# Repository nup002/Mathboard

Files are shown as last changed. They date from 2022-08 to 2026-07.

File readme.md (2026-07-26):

# Mathpad
### Get yours on [Crowd Supply](https://www.crowdsupply.com/summa-cogni/mathpad) or [Tindie](https://www.tindie.com/products/summacogni/mathpad/)
<div align="center">
  <table border="0" cellspacing="0" cellpadding="0" style="border-collapse: collapse;">
    <tr>
      <td align="center" width="33%" style="border: none;">
        <a href="https://mathpad.summacogni.com">
          Documentation
        </a><br>
        <p>Learn more about Mathpad with the 
        <a href="https://mathpad.summacogni.com">Official Documentation</a>.</p>
      </td>
      <td align="center" width="33%" style="border: none;">
        <a href="https://www.summacogni.com/forum/viewforum.php?f=3&sid=dd5691a11e42b75db93c227916b067e8">
          Forum
        </a><br>
        <p>Chat with other users and ask your questions in the
        <a href="https://www.summacogni.com/forum/viewforum.php?f=3&sid=dd5691a11e42b75db93c227916b067e8">Forum</a>.</p>
      </td>
      <td align="center" width="33%" style="border: none;">
        <a href="https://x.com/SummaCogni">
          Twitter/X
        </a><br>
        <p>Get the latest updates about Mathpad on
        <a href="https://x.com/SummaCogni">Twitter/X</a>.</p>
      </td>
    </tr>
  </table>
</div>
<p align="center">
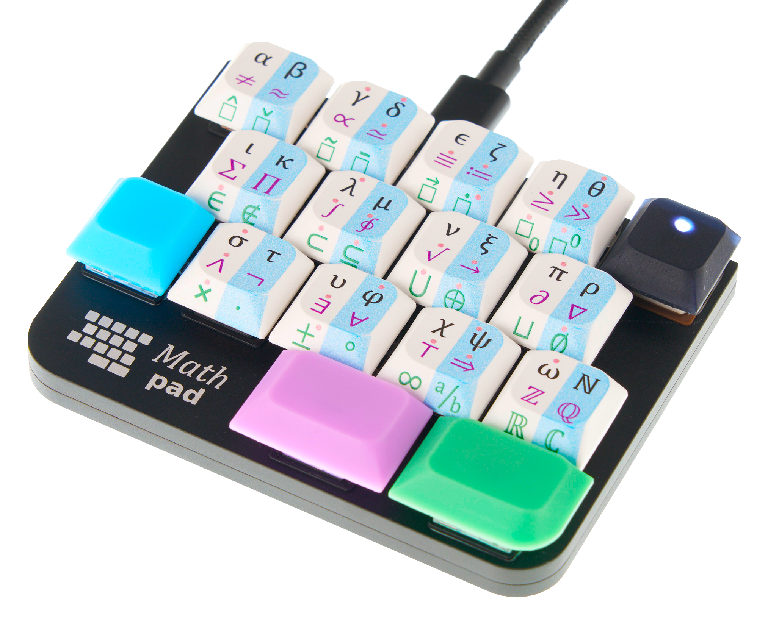
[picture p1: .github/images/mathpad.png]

</p>

## What is it?
Mathpad is a keypad that makes it easy to type equations. It is intended for engineers, 
scientists, students, and professionals in STEM fields who regularly need to write equations or who use 
mathematical symbols in their day-to-day work. 

With the Mathpad you can type 120 symbols from algebra, calculus, set theory, and 
logic, and the full greek alphabet. Mathpad plugs into your computer with a USB-C cable and 
works seamlessly alongside your regular keyboard.

The following equations are a few examples of what you can 
type directly with the Mathpad:

<p style="text-align: center;"><font size="4"> 
E = mc²<br>
∛β ≫ ∯Ω(t)dt<br>
(A⊂B) ∧ (A⊂C) ⇔ A ⊂ (B ∪ C)
</font> </p>

## Where to buy
Mathpad is available now on [Crowd Supply](https://www.crowdsupply.com/summa-cogni/mathpad) and [Tindie](https://www.tindie.com/products/summacogni/mathpad/).

### Which site should I use?
- USA customers: Buy from Crowd Supply
- International customers: Buy from Tindie

### Why the price difference?
Crowd Supply is a US-based reseller that handles distribution but must factor in import tariffs and retail margins, which increases the price. Tindie is a marketplace where I sell directly to you with lower platform fees and no US import tariffs for international buyers, resulting in a lower price.

## Compatibility
Mathpad works on Windows, macOS, and virtually all Unix systems.

Several output modes are supported. Plaintext outputs standard Unicode symbols and can be used practically anywhere you can type regular text. LaTeX is 
of course also supported, as well as the equation editors of Microsoft Office and LibreOffice.
| Output mode | Supported |
|---|---|
| Plaintext | ✅ |
| LaTeX | ✅ |
| Microsoft Office equation editor | ✅ |
| LibreOffice equation editor | ✅ |

Mathpad works on all computers with Latin keyboard layouts. This includes nearly all western layouts, including 
US ANSI, UK, French AZERTY, DVORAK, and many more. For a full list of all supported keyboard layouts, 
see [this list](https://mathpad.summacogni.com/#/compatibility?id=supported-keyboard-layouts).

## Firmware releases
Official releases are located in [releases](https://github.com/Summa-Cogni/Mathpad/releases). The most recent version can always be found [here](https://mathpad.summacogni.com/#/firmware-download).

If you wish to build the firmware binaries yourself, follow [this guide](https://mathpad.summacogni.com/#/firmware_prerequisites) from the official documentation.

## Licenses
<p align="center">

</p>

Everyone is permitted to replicate the Mathpad based on the design files found in this repository. Everyone is
 permitted to modify, share, and distribute the files, as long as the terms set out in the licenses are respected.

The Summa Cogni logo and the Mathpad logo are the properties of Summacogni OÜ, and may not be replicated.

The OSHWA certification ID `UK000074` is issued to Summacogni OÜ, and may not be replicated.

## Certifications
Mathpad is [certified](https://certification.oshwa.org/uk000074.html) by the Open Source Hardware Association.
<p align="center">
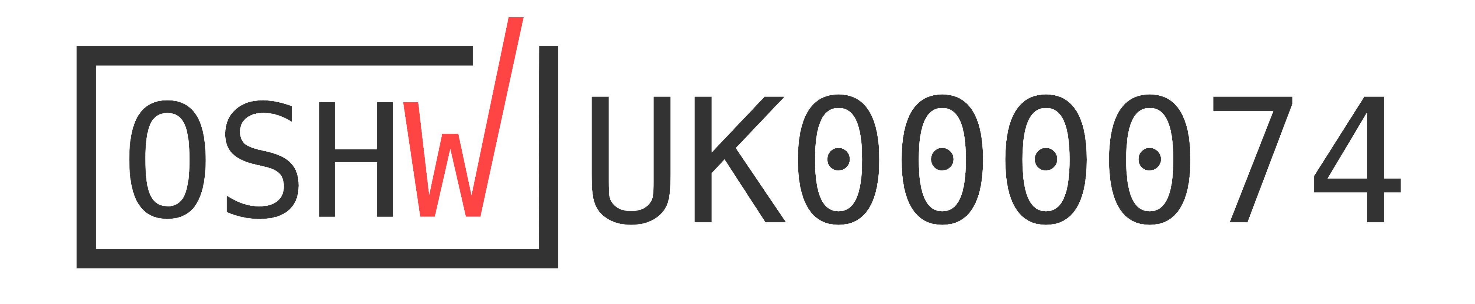
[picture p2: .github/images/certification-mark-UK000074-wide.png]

</p>

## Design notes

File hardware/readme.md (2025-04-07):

# Hardware resources

This folder contains everything related to the hardware of the Mathpad:
- Enclosure
- Keycaps
- Printed circuit board

The files contained in this folder are licensed under [CERN Open Hardware Licence Version 2 - Strongly Reciprocal](https://cern-ohl.web.cern.ch).

## What you CAN do:
- Use the design files to make products for yourself
- Modify the design files to suit your needs
- Share and distribute the original design files
- Share and distribute your modified design files
- Use the designs commercially and sell products you make

## What you MUST do:
- Keep all the original license notices and copyright information
- If you modify the files, add a notice stating what you changed and when
- When sharing products you've made, you must either:
	1) Provide the complete source files with the product, OR
	2) Clearly inform recipients where they can get the complete source files
- License any modifications you make under the same CERN-OHL-S license
- Display the source location on the product itself if specified in a notice

## What you CANNOT do:
- Remove or alter the original license notices
- Use a different license for your modifications
- Restrict others from exercising the rights granted by this license
- Hold the original creators liable for any issues with the designs

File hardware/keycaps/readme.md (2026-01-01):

# Keycaps

This folder contains the design files required to create the keycaps.

Symbol keycaps
-----------
The symbol keys use JWA keycap profiles. These can be purchased online or 3D printed using `cad files\JWA-1u.stl`. 
The decals are located in the `decals` folder and must be UV-printed onto the keycaps.

Modifier keycaps
-------------
The bottom modifier switches use 1.5u JWA keycap profiles. These must be 3D printed using `cad files\JWA-1-5u.stl` and `cad files\JWA-1-5u-rounded.stl`.

Mode switch keycap
------------------
The mode switch keycap consist of two pieces that click together: `cad files\JWA-1u-Mode-Switch.stl` and `cad files\Mode-Switch-Insert.stl`.

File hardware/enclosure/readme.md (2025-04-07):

# Mathpad enclosure

This folder contains all design files for the aluminum enclosure of the Mathpad. 

CAD files are provided in `.step` format and are located in the folder `cad files`.

Laser engraving files are provided in `.svg` format and are located in the folder `laser engraving`.

## Manufacturing specifications
- Material	: Aluminium 6061 or similar
- Surface 	: As machined
- Finish  	: Matte black anodization with laser marking
- Tapped holes  : 4 M2x0.4
- Tolerances	: ISO2768 medium

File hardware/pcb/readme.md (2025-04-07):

Mathpad PCB
###########

This folder contains the schematics and design files for the Mathpad PCB.

The folder `kicad` contains the full KiCAD project file. Download the open source [KiCAD EDA](https://www.kicad.org) to open it.

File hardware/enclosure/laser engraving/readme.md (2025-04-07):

# Laser engraving

This folder contains the file `mathpad_laser_engraving_back.svg` which is used to perform laser engraving of the 
symbols, labels, and other features on the back of the Mathpad.

The folder `enclosure outlines` contain SVG files of the outline of the Mathpad as seen from the top and the bottom, 
and can be used for developing new laser engraving designs.

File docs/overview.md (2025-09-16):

# Overview

On the back there is the OS switch, an LED indicating if the 
Mathpad is powered, and the USB-C port.



The top of Mathpad has many keys. There are 3 rows of symbol keys, three colored Modifier keys, and the  
[Mode key](/modes.md).



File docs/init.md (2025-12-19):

# Initial Setup

**Mathpad works straight out of the box in many cases.** But depending on your operating system and keyboard layout, 
there are a few initial tasks that may have to be performed. Follow this short guide to get your Mathpad up and running.

## What operating system do you use?

<!-- tabs:start -->
#### **Mac**

1) Install [Mathpad Service](https://github.com/Summa-Cogni/Mathpad/releases/download/mathpad-service-v1.1.0/mathpad-service-1.1.0.dmg) - this small application enables Mathpad to insert Unicode symbols on Mac.
2) Set the OS switch on the back of your Mathpad to the MAC position

#### **Windows**

1) Install [WinCompose](http://wincompose.info) - this enables special character input on Windows
2) Set the OS switch on the back of your Mathpad to the WINDOWS position

> [!TIP]
> If you cannot install WinCompose, for example if your computer is managed by an IT department and you 
> lack administrator rights, use the [portable executable](https://github.com/samhocevar/wincompose/releases/download/v0.9.10/WinCompose-NoInstall-0.9.10.zip).
> 
> 

#### **Linux**

1) Set the OS switch on the back of your Mathpad to the LINUX position

There's no software to install on Linux, as most distros have built-in support for Unicode input.
> 
<!-- tabs:end -->

> [!NOTE|label:Why Setting The OS Switch Is Required]
> Mathpad transmits symbols using Unicode. Since each operating system handles Unicode input differently, Mathpad needs 
> to adjust its data format based on the connected operating system. USB devices like Mathpad cannot detect your 
> computer's operating system automatically, so you must specify it with the OS switch.
> 
> 
## What is your keyboard layout?
<!-- tabs:start -->

#### **US ANSI (standard layout in USA)**

You're good to go! Mathpad supports US ANSI out of the box. You can move on to [Getting Started](/get_started.md).

> [!TIP]
> You may still want to update your Mathpad's firmware to the newest version to benefit from 
> new features and bugfixes. Do so by following the instructions in the [Firmware Update Guide](update_firmware.md).
> 

#### **Any other layout**

**You must update your Mathpad's firmware to match your computer's keyboard layout.** 
1) Follow the instructions in the [Firmware Update Guide](update_firmware.md)
2) Once you've updated your Mathpad's firmware, move on to [Getting Started](/get_started.md).

> [!TIP]
>Your keyboard layout is usually defined in the "Input devices" or "Language and Region" settings. Check out this 
> [guide](/compatibility.md#how-to-check-your-layout) if you need some extra help.
> 
<!-- tabs:end -->

> [!NOTE|label:Why Layout Matching Is Required]
>Your Mathpad's firmware must match your computer's keyboard layout. This is necessary because operating systems 
> interpret keyboard signals differently based on layout settings, and USB devices like Mathpad cannot detect your 
> computer's layout automatically. 
> 
> Keyboards do not send actual letters. Instead they send 'keycodes' which are interpreted into symbols by the 
> OS. When a Norwegian keyboard user clicks the key for 'å', the letter 'å' is never sent. Instead, the keyboard sends 
> the keycode for 'left bracket' (`[`) which is then interpreted as 'å' by the OS.

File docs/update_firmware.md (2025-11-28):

# Updating the Firmware

Firmware is the code that runs on the processor inside the Mathpad. You must sometimes update this firmware, 
for example when:
- You set up your Mathpad for the first time
- You change the keyboard layout on your computer
- You want to use a feature in a new firmware release
- You make your own modifications to the firmware

> [!TIP|label: Get your current firmware version]
> In a text editor, keep all the modifier keys ([R], [C] and [B]) pressed for at least 5 seconds, then release them.
> Your Mathpad will type a lot of information about itself, including its firmware version.
> 

**Updating the Mathpad firmware is safe and very simple**. It requires no previous experience or special 
tools. Just follow these three steps:

### Step 1: Download your firmware
Head over to the [Firmware Download](firmware-download.md) page and download the firmware that matches your keyboard 
layout.

### Step 2: Put your Mathpad in firmware upload mode
With your Mathpad plugged in, flip it over and use something long and thin (e.g. a pen) to press the 
Restart button for at least half a second, then release it. The Restart button is located here:



### Step 3: Drag and drop the firmware file
When you release the Restart button, a folder named `RPI-RP2` with a two files inside should appear automatically on 
your computer. Grab the firmware file you just downloaded, and drag-and-drop (or copy-paste) it to the `RPI-RP2` 
folder. Once the file has been transferred, the folder will close automatically. You're done!

> [!TIP|label:No RPI-RP2 folder]
> If the `RPI-RP2` folder does not appear, try keeping the Restart button pressed longer before releasing it. You 
> should also look under "This PC" on Windows, or "Computer" on Mac.
>

> [!TIP]
> The Mathpad is **not** a storage device like a USB memory stick - do not expect to find the firmware file in the 
> `RPI-RP2` folder after you have uploaded it.
>

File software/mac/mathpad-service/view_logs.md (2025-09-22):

# View current logs
tail -f /usr/local/var/log/mathpad-service.log

# View error logs  
tail -f /usr/local/var/log/mathpad-service.error.log

# Start service manually
/usr/local/bin/start-mathpad-service

# Stop service
pkill -f mathpad-service

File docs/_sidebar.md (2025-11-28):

- Quick Start
  * [Initial Setup](init.md "Setting up your Mathpad for the first time")
  * [Getting Started](get_started.md "Getting started with using your Mathpad")
  * [Device Overview](overview.md "What's what on Mathpad")

- User Guide
  * [Symbols Reference](symbols.md "A comprehensive list of all Mathpad symbols")
  * [Multitap Feature](multitap.md "Access hidden symbols")
  * [Output Modes](modes.md "Switch between Plaintext, LaTeX, and more")
  * [Update Firmware](update_firmware.md "Update the firmware of your Mathpad")
  * [Troubleshooting](troubleshoot.md "Fix common problems")
  * [Compatibility](compatibility.md "View OS and keyboard layout compatibility")

- Downloads
  * [Firmware](firmware-download.md "Download Mathpad firmware")
  * [Software](software-download.md "Download Mathpad software")

- Advanced Topics
  * [Firmware Prerequisites](firmware_prerequisites.md "Get ready to modify the Mathpad firmware")
  * [Firmware Manual](firmware.md "Learn how to modify the Mathpad firmware")
  * [Firmware Compilation](compile.md "Learn how to compile the Mathpad firmware")

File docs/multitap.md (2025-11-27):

# Multitap

Many symbols are marked by a small orange dot. Tapping such a symbol twice quickly will type a different 
but related symbol. For example, double-tapping <keycombo>[δ]</keycombo> types its uppercase variant Δ. The notation 
for this action is <keycombo>[δ][x2]</keycombo>.



Certain symbols can be triple-tapped. For example, to type ∜ you must triple-tap <keycombo>[√]</keycombo>. 
Double-tapping it types ∛.

To multitap a symbol that requires the use of modifier keys, you must keep the modifier keys pressed and only multitap 
the symbol key. For example, to get ≅, you must keep [R] and [C] pressed while you tap <keycombo>[≃]</keycombo> twice 
quickly.

Try multitapping some symbols in the text editor below to get used to it. 
<div class="keyboard-test-container">
  <div class="input-area">
    <textarea rows="1" cols="20" style="font-family:'Cambria Math';font-size: 30pt"></textarea>
  </div>
</div>

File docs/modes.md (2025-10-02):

# Output Modes

The default output mode of Mathpad is Plaintext. In Plaintext mode, Mathpad outputs simple Unicode symbols. This mode 
is the most versatile, and works with virtually all text editors. Mathpad is in Plaintext mode when the Mode key 
lights white.

> [!TIP]
> Change the mode key brightness by tapping it while holding down the purple or green modifier keys.
>

If you are instead working in the typesetting language LaTeX, or using the equation editors of Microsoft Office or 
LibreOffice, you'll want to switch modes by clicking the Mode key:

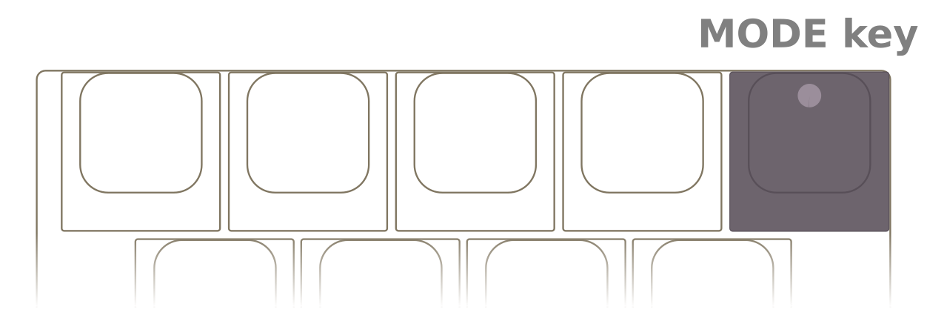
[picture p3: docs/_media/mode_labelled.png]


## LaTeX mode
**Set LaTeX mode by clicking the Mode key until it lights magenta.**

In LaTeX mode, Mathpad will type LaTeX codes. Test it here:

<div class="keyboard-test-container">
  <div class="input-area">
    <textarea id="latex-input" rows="1" cols="50" placeholder="Click here and type"></textarea>
  </div>
  <div class="render-area">
    
  </div>
</div>

<style>
.keyboard-test-container {
  margin: 20px 0;
  display: flex;
  flex-direction: column;
  gap: 15px;
}
.input-area, .render-area {
  width: 100%;
}
#latex-input {
  width: 100%;
  padding: 10px;
  font-family: monospace;
  border: 1px solid #ccc;
  border-radius: 4px;
}
#latex-output {
  padding: 15px;
  min-height: 100px;
  border: 1px solid #eee;
  border-radius: 4px;
  background: #f9f9f9;
  font-size: 3em; /* Adjust the size as needed */
}
</style>

> [!TIP]
> You can always get Mathpad back to Plaintext mode by holding down the Mode key for one second and releasing it.
>

## Microsoft Office Equation Editor mode
**Set Microsoft Office mode by clicking the Mode key until it lights blue.** 

In this mode, Mathpad will type codes 
that works specifically with the equation editor that is built into many Microsoft Office applications, such as Word.

## LibreOffice Equation Editor mode
**Set LibreOffice mode by clicking the Mode key until it lights green.**

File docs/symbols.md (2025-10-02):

# Mathpad Symbols

Every symbol that can be typed with the Mathpad is listed here. 

## Lowercase Greek Letters
<div class="symbols-grid">
  <div class="symbol-card">
    <div class="symbol">α</div>
    <div class="name">Alpha</div>
    <div class="details">
      <div class="key-combo"><keycombo>[α]</keycombo></div>
    </div>
  </div>
  <div class="symbol-card">
    <div class="symbol">β</div>
    <div class="name">Beta</div>
    <div class="details">
      <div class="key-combo"><keycombo>[R]+[α]</keycombo></div>
    </div>
  </div>
  <div class="symbol-card">
    <div class="symbol">γ</div>
    <div class="name">Gamma</div>
    <div class="details">
      <div class="key-combo"><keycombo>[γ]</keycombo></div>
    </div>
  </div>
  <div class="symbol-card">
    <div class="symbol">δ</div>
    <div class="name">Delta</div>
    <div class="details">
      <div class="key-combo"><keycombo>[R]+[γ]</keycombo></div>
    </div>
  </div>
  <div class="symbol-card">
    <div class="symbol">ϵ</div>
    <div class="name">Epsilon</div>
    <div class="details">
      <div class="key-combo"><keycombo>[ϵ]</keycombo></div>
    </div>
  </div>
  <div class="symbol-card">
    <div class="symbol">ζ</div>
    <div class="name">Zeta</div>
    <div class="details">
      <div class="key-combo"><keycombo>[R]+[ϵ]</keycombo></div>
    </div>
  </div>
  <div class="symbol-card">
    <div class="symbol">η</div>
    <div class="name">Eta</div>
    <div class="details">
      <div class="key-combo"><keycombo>[η]</keycombo></div>
    </div>
  </div>
  <div class="symbol-card">
    <div class="symbol">θ</div>
    <div class="name">Theta</div>
    <div class="details">
      <div class="key-combo"><keycombo>[R]+[η]</keycombo></div>
    </div>
  </div>
  <div class="symbol-card">
    <div class="symbol">ι</div>
    <div class="name">Iota</div>
    <div class="details">
      <div class="key-combo"><keycombo>[ι]</keycombo></div>
    </div>
  </div>
  <div class="symbol-card">
    <div class="symbol">κ</div>
    <div class="name">Kappa</div>
    <div class="details">
      <div class="key-combo"><keycombo>[R]+[κ]</keycombo></div>
    </div>
  </div>
  <div class="symbol-card">
    <div class="symbol">λ</div>
    <div class="name">Lambda</div>
    <div class="details">
      <div class="key-combo"><keycombo>[λ]</keycombo></div>
    </div>
  </div>
  <div class="symbol-card">
    <div class="symbol">μ</div>
    <div class="name">Mu</div>
    <div class="details">
      <div class="key-combo"><keycombo>[R]+[μ]</keycombo></div>
    </div>
  </div>
  <div class="symbol-card">
    <div class="symbol">ν</div>
    <div class="name">Nu</div>
    <div class="details">
      <div class="key-combo"><keycombo>[ν]</keycombo></div>
    </div>
  </div>
  <div class="symbol-card">
    <div class="symbol">ξ</div>
    <div class="name">Xi</div>
    <div class="details">
      <div class="key-combo"><keycombo>[R]+[ξ]</keycombo></div>
    </div>
  </div>
  <div class="symbol-card">
    <div class="symbol">π</div>
    <div class="name">Pi</div>
    <div class="details">
      <div class="key-combo"><keycombo>[π]</keycombo></div>
    </div>
  </div>
  <div class="symbol-card">
    <div class="symbol">ρ</div>
    <div class="name">Rho</div>
    <div class="details">
      <div class="key-combo"><keycombo>[R]+[ρ]</keycombo></div>
    </div>
  </div>
  <div class="symbol-card">
    <div class="symbol">σ</div>
    <div class="name">Sigma</div>
    <div class="details">
      <div class="key-combo"><keycombo>[σ]</keycombo></div>
    </div>
  </div>
  <div class="symbol-card">
    <div class="symbol">τ</div>
    <div class="name">Tau</div>
    <div class="details">
      <div class="key-combo"><keycombo>[R]+[τ]</keycombo></div>
    </div>
  </div>
  <div class="symbol-card">
    <div class="symbol">υ</div>
    <div class="name">Upsilon</div>
    <div class="details">
      <div class="key-combo"><keycombo>[υ]</keycombo></div>
    </div>
  </div>
  <div class="symbol-card">
    <div class="symbol">φ</div>
    <div class="name">Phi</div>
    <div class="details">
      <div class="key-combo"><keycombo>[R]+[φ]</keycombo></div>
    </div>
  </div>
  <div class="symbol-card">
    <div class="symbol">χ</div>
    <div class="name">Chi</div>
    <div class="details">
      <div class="key-combo"><keycombo>[χ]</keycombo></div>
    </div>
  </div>
  <div class="symbol-card">
    <div class="symbol">ψ</div>
    <div class="name">Psi</div>
    <div class="details">
      <div class="key-combo"><keycombo>[R]+[ψ]</keycombo></div>
    </div>
  </div>
  <div class="symbol-card">
    <div class="symbol">ω</div>
    <div class="name">Omega</div>
    <div class="details">
      <div class="key-combo"><keycombo>[ω]</keycombo></div>
    </div>
  </div>
</div>

## Uppercase Greek Letters
<div class="symbols-grid">
  <div class="symbol-card">
    <div class="symbol">Γ</div>
    <div class="name">Gamma (uppercase)</div>
    <div class="details">
      <div class="key-combo"><keycombo>[γ][x2]</keycombo></div>
    </div>
  </div>
  <div class="symbol-card">
    <div class="symbol">Δ</div>
    <div class="name">Delta (uppercase)</div>
    <div class="details">
      <div class="key-combo"><keycombo>[R]+[δ][x2]</keycombo></div>
    </div>
  </div>
  <div class="symbol-card">
    <div class="symbol">Θ</div>
    <div class="name">Theta (uppercase)</div>
    <div class="details">
      <div class="key-combo"><keycombo>[R]+[θ][x2]</keycombo></div>
    </div>
  </div>
  <div class="symbol-card">
    <div class="symbol">Λ</div>
    <div class="name">Lambda (uppercase)</div>
    <div class="details">
      <div class="key-combo"><keycombo>[λ][x2]</keycombo></div>
    </div>
  </div>
  <div class="symbol-card">
    <div class="symbol">Ξ</div>
    <div class="name">Xi (uppercase)</div>
    <div class="details">
      <div class="key-combo"><keycombo>[R]+[ξ][x2]</keycombo></div>
    </div>
  </div>
  <div class="symbol-card">
    <div class="symbol">Π</div>
    <div class="name">Pi (uppercase)</div>
    <div class="details">
      <div class="key-combo"><keycombo>[π][x2]</keycombo></div>
    </div>
  </div>
  <div class="symbol-card">
    <div class="symbol">Σ</div>
    <div class="name">Sigma (uppercase)</div>
    <div class="details">
      <div class="key-combo"><keycombo>[σ][x2]</keycombo></div>
    </div>
  </div>
  <div class="symbol-card">
    <div class="symbol">Φ</div>
    <div class="name">Phi (uppercase)</div>
    <div class="details">
      <div class="key-combo"><keycombo>[R]+[φ][x2]</keycombo></div>
    </div>
  </div>
  <div class="symbol-card">
    <div class="symbol">Ψ</div>
    <div class="name">Psi (uppercase)</div>
    <div class="details">
      <div class="key-combo"><keycombo>[R]+[ψ][x2]</keycombo></div>
    </div>
  </div>
  <div class="symbol-card">
    <div class="symbol">Ω</div>
    <div class="name">Omega (uppercase)</div>
    <div class="details">
      <div class="key-combo"><keycombo>[ω][x2]</keycombo></div>
    </div>
  </div>
</div>

## Relationships
<div class="symbols-grid">
  <div class="symbol-card">
    <div class="symbol">≠</div>
    <div class="name">Not equal</div>
    <div class="details">
      <div class="key-combo"><keycombo>[C]+[α]</keycombo></div>
    </div>
  </div>
  <div class="symbol-card">
    <div class="symbol">≈</div>
    <div class="name">Approximately equal</div>
    <div class="details">
      <div class="key-combo"><keycombo>[R][C]+[α]</keycombo></div>
    </div>
  </div>
  <div class="symbol-card">
    <div class="symbol">∝</div>
    <div class="name">Proportional to</div>
    <div class="details">
      <div class="key-combo"><keycombo>[C]+[γ]</keycombo></div>
    </div>
  </div>
  <div class="symbol-card">
    <div class="symbol">≃</div>
    <div class="name">Asymptotically equal</div>
    <div class="details">
      <div class="key-combo"><keycombo>[R][C]+[γ]</keycombo></div>
    </div>
  </div>
  <div class="symbol-card">
    <div class="symbol">≅</div>
    <div class="name">Approximately equal</div>
    <div class="details">
      <div class="key-combo"><keycombo>[R][C]+[γ][x2]</keycombo></div>
    </div>
  </div>
  <div class="symbol-card">
    <div class="symbol">≡</div>
    <div class="name">Identical to</div>
    <div class="details">
      <div class="key-combo"><keycombo>[C]+[ϵ]</keycombo></div>
    </div>
  </div>
  <div class="symbol-card">
    <div class="symbol">≣</div>
    <div class="name">Strictly equivalent to</div>
    <div class="details">
      <div class="key-combo"><keycombo>[C]+[ϵ][x2]</keycombo></div>
    </div>
  </div>
  <div class="symbol-card">
    <div class="symbol">≔</div>
    <div class="name">Definition</div>
    <div class="details">
      <div class="key-combo"><keycombo>[R][C]+[ϵ]</keycombo></div>
    </div>
  </div>
  <div class="symbol-card">
    <div class="symbol">≝</div>
    <div class="name">Definition (alternative)</div>
    <div class="details">
      <div class="key-combo"><keycombo>[R][C]+[ϵ][x2]</keycombo></div>
    </div>
  </div>
  <div class="symbol-card">
    <div class="symbol">≥</div>
    <div class="name">Greater or equal</div>
    <div class="details">
      <div class="key-combo"><keycombo>[C]+[η]</keycombo></div>
    </div>
  </div>
  <div class="symbol-card">
    <div class="symbol">≤</div>
    <div class="name">Less or equal</div>
    <div class="details">
      <div class="key-combo"><keycombo>[C]+[η][x2]</keycombo></div>
    </div>
  </div>
  <div class="symbol-card">
    <div class="symbol">≫</div>
    <div class="name">Much greater</div>
    <div class="details">
      <div class="key-combo"><keycombo>[R][C]+[η]</keycombo></div>
    </div>
  </div>
  <div class="symbol-card">
    <div class="symbol">≪</div>
    <div class="name">Much less</div>
    <div class="details">
      <div class="key-combo"><keycombo>[R][C]+[η][x2]</keycombo></div>
    </div>
  </div>
</div>

## Calculus
<div class="symbols-grid">
  <div class="symbol-card">
    <div class="symbol">∑</div>
    <div class="name">Summation</div>
    <div class="details">
      <div class="key-combo"><keycombo>[C]+[ι]</keycombo></div>
    </div>
  </div>
  <div class="symbol-card">
    <div class="symbol">∏</div>
    <div class="name">Product</div>
    <div class="details">
      <div class="key-combo"><keycombo>[R][C]+[ι]</keycombo></div>
    </div>
  </div>
  <div class="symbol-card">
    <div class="symbol">∫</div>
    <div class="name">Integral</div>
    <div class="details">
      <div class="key-combo"><keycombo>[C]+[λ]</keycombo></div>
    </div>
  </div>
  <div class="symbol-card">
    <div class="symbol">∬</div>
    <div class="name">Double integral</div>
    <div class="details">
      <div class="key-combo"><keycombo>[C]+[λ][x2]</keycombo></div>
    </div>
  </div>
  <div class="symbol-card">
    <div class="symbol">∭</div>
    <div class="name">Triple integral</div>
    <div class="details">
      <div class="key-combo"><keycombo>[C]+[λ][x3]</keycombo></div>
    </div>
  </div>
  <div class="symbol-card">
    <div class="symbol">∮</div>
    <div class="name">Contour integral</div>
    <div class="details">
      <div class="key-combo"><keycombo>[R][C]+[λ]</keycombo></div>
    </div>
  </div>
  <div class="symbol-card">
    <div class="symbol">∯</div>
    <div class="name">Surface integral</div>
    <div class="details">
      <div class="key-combo"><keycombo>[R][C]+[λ][x2]</keycombo></div>
    </div>
  </div>
  <div class="symbol-card">
    <div class="symbol">∰</div>
    <div class="name">Volume integral</div>
    <div class="details">
      <div class="key-combo"><keycombo>[R][C]+[λ][x3]</keycombo></div>
    </div>
  </div>
  <div class="symbol-card">
    <div class="symbol">√</div>
    <div class="name">Square root</div>
    <div class="details">
      <div class="key-combo"><keycombo>[C]+[ν]</keycombo></div>
    </div>
  </div>
  <div class="symbol-card">
    <div class="symbol">∛</div>
    <div class="name">Cube root</div>
    <div class="details">
      <div class="key-combo"><keycombo>[C]+[ν][x2]</keycombo></div>
    </div>
  </div>
  <div class="symbol-card">
    <div class="symbol">∜</div>
    <div class="name">Quadratic root</div>
    <div class="details">
      <div class="key-combo"><keycombo>[C]+[ν][x3]</keycombo></div>
    </div>
  </div>
  <div class="symbol-card">
    <div class="symbol">∂</div>
    <div class="name">Partial differential</div>
    <div class="details">
      <div class="key-combo"><keycombo>[C]+[π]</keycombo></div>
    </div>
  </div>
  <div class="symbol-card">
    <div class="symbol">∇</div>
    <div class="name">Nabla</div>
    <div class="details">
      <div class="key-combo"><keycombo>[R][C]+[π]</keycombo></div>
    </div>
  </div>
</div>

## Logic
<div class="symbols-grid">
  <div class="symbol-card">
    <div class="symbol">∧</div>
    <div class="name">Logical And</div>
    <div class="details">
      <div class="key-combo"><keycombo>[C]+[σ]</keycombo></div>
    </div>
  </div>
  <div class="symbol-card">
    <div class="symbol">∨</div>
    <div class="name">Logical Or</div>
    <div class="details">
      <div class="key-combo"><keycombo>[C]+[σ][x2]</keycombo></div>
    </div>
  </div>
  <div class="symbol-card">
    <div class="symbol">¬</div>
    <div class="name">Not</div>
    <div class="details">
      <div class="key-combo"><keycombo>[R][C]+[σ]</keycombo></div>
    </div>
  </div>
  <div class="symbol-card">
    <div class="symbol">∃</div>
    <div class="name">There Exists</div>
    <div class="details">
      <div class="key-combo"><keycombo>[C]+[υ]</keycombo></div>
    </div>
  </div>
  <div class="symbol-card">
    <div class="symbol">∄</div>
    <div class="name">There Does Not Exist</div>
    <div class="details">
      <div class="key-combo"><keycombo>[C]+[υ][x2]</keycombo></div>
    </div>
  </div>
  <div class="symbol-card">
    <div class="symbol">∀</div>
    <div class="name">For all</div>
    <div class="details">
      <div class="key-combo"><keycombo>[R][C]+[υ]</keycombo></div>
    </div>
  </div>
  <div class="symbol-card">
    <div class="symbol">⊤</div>
    <div class="name">Down tack</div>
    <div class="details">
      <div class="key-combo"><keycombo>[C]+[χ]</keycombo></div>
    </div>
  </div>
  <div class="symbol-card">
    <div class="symbol">⊥</div>
    <div class="name">Up Tack</div>
    <div class="details">
      <div class="key-combo"><keycombo>[C]+[χ][x2]</keycombo></div>
    </div>
  </div>
</div>

## Arrows
<div class="symbols-grid">
  <div class="symbol-card">
    <div class="symbol">→</div>
    <div class="name">Right arrow</div>
    <div class="details">
      <div class="key-combo"><keycombo>[R][C]+[ν]</keycombo></div>
    </div>
  </div>
  <div class="symbol-card">
    <div class="symbol">↔</div>
    <div class="name">Left Right arrow</div>
    <div class="details">
      <div class="key-combo"><keycombo>[R][C]+[ν][x2]</keycombo></div>
    </div>
  </div>
  <div class="symbol-card">
    <div class="symbol">←</div>
    <div class="name">Left arrow</div>
    <div class="details">
      <div class="key-combo"><keycombo>[R][C]+[ν][x3]</keycombo></div>
    </div>
  </div>
  <div class="symbol-card">
    <div class="symbol">⇒</div>
    <div class="name">Right double arrow</div>
    <div class="details">
      <div class="key-combo"><keycombo>[R][C]+[χ]</keycombo></div>
    </div>
  </div>
  <div class="symbol-card">
    <div class="symbol">⇔</div>
    <div class="name">Left Right double arrow</div>
    <div class="details">
      <div class="key-combo"><keycombo>[R][C]+[χ][x2]</keycombo></div>
    </div>
  </div>
  <div class="symbol-card">
    <div class="symbol">⇐</div>
    <div class="name">Left double arrow</div>
    <div class="details">
      <div class="key-combo"><keycombo>[R][C]+[χ][x3]</keycombo></div>
    </div>
  </div>
</div>

## Diacritics
<div class="symbols-grid">
  <div class="symbol-card">
    <div class="symbol">^</div>
    <div class="name">Hat</div>
    <div class="details">
      <div class="key-combo"><keycombo>[B]+[α]</keycombo></div>
    </div>
  </div>
  <div class="symbol-card">
    <div class="symbol">ˇ</div>
    <div class="name">Check</div>
    <div class="details">
      <div class="key-combo"><keycombo>[R][B]+[α]</keycombo></div>
    </div>
  </div>
  <div class="symbol-card">
    <div class="symbol">~</div>
    <div class="name">Tilde</div>
    <div class="details">
      <div class="key-combo"><keycombo>[B]+[γ]</keycombo></div>
    </div>
  </div>
  <div class="symbol-card">
    <div class="symbol">¯</div>
    <div class="name">Overbar</div>
    <div class="details">
      <div class="key-combo"><keycombo>[R][B]+[γ]</keycombo></div>
    </div>
  </div>
  <div class="symbol-card">
    <div class="symbol">⃗</div>
    <div class="name">Arrow</div>
    <div class="details">
      <div class="key-combo"><keycombo>[B]+[ϵ]</keycombo></div>
    </div>
  </div>
  <div class="symbol-card">
    <div class="symbol">˙</div>
    <div class="name">Dot</div>
    <div class="details">
      <div class="key-combo"><keycombo>[R][B]+[ϵ]</keycombo></div>
    </div>
  </div>
  <div class="symbol-card">
    <div class="symbol">¨</div>
    <div class="name">Double dot</div>
    <div class="details">
      <div class="key-combo"><keycombo>[R][B]+[ϵ][x2]</keycombo></div>
    </div>
  </div>
  <div class="symbol-card">
    <div class="symbol">⃛</div>
    <div class="name">Triple dot</div>
    <div class="details">
      <div class="key-combo"><keycombo>[R][B]+[ϵ][x3]</keycombo></div>
    </div>
  </div>
</div>

## Subscript / Superscript
<div class="symbols-grid">
  <div class="symbol-card">
    <div class="symbol">₀</div>
    <div class="name">Subscript 0</div>
    <div class="details">
      <div class="key-combo"><keycombo>[B]+[η]</keycombo></div>
    </div>
  </div>
  <div class="symbol-card">
    <div class="symbol">₁</div>
    <div class="name">Subscript 1</div>
    <div class="details">
      <div class="key-combo"><keycombo>[B]+[η][x2]</keycombo></div>
    </div>
  </div>
  <div class="symbol-card">
    <div class="symbol">₂</div>
    <div class="name">Subscript 2</div>
    <div class="details">
      <div class="key-combo"><keycombo>[B]+[η][x3]</keycombo></div>
    </div>
  </div>
  <div class="symbol-card">
    <div class="symbol">⁰</div>
    <div class="name">Superscript 0</div>
    <div class="details">
      <div class="key-combo"><keycombo>[R][B]+[η]</keycombo></div>
    </div>
  </div>
  <div class="symbol-card">
    <div class="symbol">¹</div>
    <div class="name">Superscript 1</div>
    <div class="details">
      <div class="key-combo"><keycombo>[R][B]+[η][x2]</keycombo></div>
    </div>
  </div>
  <div class="symbol-card">
    <div class="symbol">²</div>
    <div class="name">Superscript 2</div>
    <div class="details">
      <div class="key-combo"><keycombo>[R][B]+[η][x3]</keycombo></div>
    </div>
  </div>
</div>

## Set Theory
<div class="symbols-grid">
  <div class="symbol-card">
    <div class="symbol">∈</div>
    <div class="name">Element of</div>
    <div class="details">
      <div class="key-combo"><keycombo>[B]+[ι]</keycombo></div>
    </div>
  </div>
  <div class="symbol-card">
    <div class="symbol">∋</div>
    <div class="name">Contains as member</div>
    <div class="details">
      <div class="key-combo"><keycombo>[B]+[ι][x2]</keycombo></div>
    </div>
  </div>
  <div class="symbol-card">
    <div class="symbol">∉</div>
    <div class="name">Not an element of</div>
    <div class="details">
      <div class="key-combo"><keycombo>[R][B]+[ι]</keycombo></div>
    </div>
  </div>
  <div class="symbol-card">
    <div class="symbol">⊂</div>
    <div class="name">Proper Subset</div>
    <div class="details">
      <div class="key-combo"><keycombo>[B]+[λ]</keycombo></div>
    </div>
  </div>
  <div class="symbol-card">
    <div class="symbol">⊄</div>
    <div class="name">Not proper subset</div>
    <div class="details">
      <div class="key-combo"><keycombo>[B]+[λ][x2]</keycombo></div>
    </div>
  </div>
  <div class="symbol-card">
    <div class="symbol">⊆</div>
    <div class="name">Subset</div>
    <div class="details">
      <div class="key-combo"><keycombo>[R][B]+[λ]</keycombo></div>
    </div>
  </div>
  <div class="symbol-card">
    <div class="symbol">⊈</div>
    <div class="name">Not subset</div>
    <div class="details">
      <div class="key-combo"><keycombo>[R][B]+[λ][x2]</keycombo></div>
    </div>
  </div>
  <div class="symbol-card">
    <div class="symbol">∪</div>
    <div class="name">Union</div>
    <div class="details">
      <div class="key-combo"><keycombo>[B]+[ν]</keycombo></div>
    </div>
  </div>
  <div class="symbol-card">
    <div class="symbol">∩</div>
    <div class="name">Intersection</div>
    <div class="details">
      <div class="key-combo"><keycombo>[B]+[ν][x2]</keycombo></div>
    </div>
  </div>
  <div class="symbol-card">
    <div class="symbol">⊕</div>
    <div class="name">Direct sum</div>
    <div class="details">
      <div class="key-combo"><keycombo>[R][B]+[ν]</keycombo></div>
    </div>
  </div>
  <div class="symbol-card">
    <div class="symbol">⊔</div>
    <div class="name">Disjoint Union</div>
    <div class="details">
      <div class="key-combo"><keycombo>[B]+[π]</keycombo></div>
    </div>
  </div>
  <div class="symbol-card">
    <div class="symbol">∅</div>
    <div class="name">Empty set</div>
    <div class="details">
      <div class="key-combo"><keycombo>[R][B]+[π]</keycombo></div>
    </div>
  </div>
</div>

## Other Symbols
<div class="symbols-grid">
  <div class="symbol-card">
    <div class="symbol">×</div>
    <div class="name">Cross product</div>
    <div class="details">
      <div class="key-combo"><keycombo>[B]+[σ]</keycombo></div>
    </div>
  </div>
  <div class="symbol-card">
    <div class="symbol">÷</div>
    <div class="name">Division</div>
    <div class="details">
      <div class="key-combo"><keycombo>[B]+[σ][x2]</keycombo></div>
    </div>
  </div>
  <div class="symbol-card">
    <div class="symbol">⋅</div>
    <div class="name">Dot product</div>
    <div class="details">
      <div class="key-combo"><keycombo>[R][B]+[σ]</keycombo></div>
    </div>
  </div>
  <div class="symbol-card">
    <div class="symbol">±</div>
    <div class="name">Plus minus</div>
    <div class="details">
      <div class="key-combo"><keycombo>[B]+[υ]</keycombo></div>
    </div>
  </div>
  <div class="symbol-card">
    <div class="symbol">∓</div>
    <div class="name">Minus plus</div>
    <div class="details">
      <div class="key-combo"><keycombo>[B]+[υ][x2]</keycombo></div>
    </div>
  </div>
  <div class="symbol-card">
    <div class="symbol">°</div>
    <div class="name">Degree</div>
    <div class="details">
      <div class="key-combo"><keycombo>[R][B]+[υ]</keycombo></div>
    </div>
  </div>
  <div class="symbol-card">
    <div class="symbol">∞</div>
    <div class="name">Infinity</div>
    <div class="details">
      <div class="key-combo"><keycombo>[B]+[χ]</keycombo></div>
    </div>
  </div>
  <div class="symbol-card">
    <div class="symbol">⁄</div>
    <div class="name">Fraction</div>
    <div class="details">
      <div class="key-combo"><keycombo>[R][B]+[χ]</keycombo></div>
    </div>
  </div>
  <div class="symbol-card">
    <div class="symbol">⊗</div>
    <div class="name">Tensor product</div>
    <div class="details">
      <div class="key-combo"><keycombo>[R][B]+[ν][x2]</keycombo></div>
    </div>
  </div>
</div>

## Number Systems
<div class="symbols-grid">
  <div class="symbol-card">
    <div class="symbol">ℕ</div>
    <div class="name">Natural numbers</div>
    <div class="details">
      <div class="key-combo"><keycombo>[R]+[ω]</keycombo></div>
    </div>
  </div>
  <div class="symbol-card">
    <div class="symbol">ℤ</div>
    <div class="name">Integer numbers</div>
    <div class="details">
      <div class="key-combo"><keycombo>[C]+[ω]</keycombo></div>
    </div>
  </div>
  <div class="symbol-card">
    <div class="symbol">ℚ</div>
    <div class="name">Rational numbers</div>
    <div class="details">
      <div class="key-combo"><keycombo>[R][C]+[ω]</keycombo></div>
    </div>
  </div>
  <div class="symbol-card">
    <div class="symbol">ℝ</div>
    <div class="name">Real numbers</div>
    <div class="details">
      <div class="key-combo"><keycombo>[B]+[ω]</keycombo></div>
    </div>
  </div>
  <div class="symbol-card">
    <div class="symbol">ℂ</div>
    <div class="name">Complex numbers</div>
    <div class="details">
      <div class="key-combo"><keycombo>[R][B]+[ω]</keycombo></div>
    </div>
  </div>
</div>

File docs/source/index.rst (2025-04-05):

Mathpad documentation
===================================
The Mathpad is a small keypad that gives you access to a wide range of mathematical symbols and the entire
lowercase and uppercase greek alphabet. It works alongside your normal keyboard, and requires no software to use
(except on Windows).

This documentation gathers all information on the Mathpad:
 - Usage
 - Troubleshooting

The Mathpad is
fully open source and can be built by nearly anyone with a few simple tools. If you wish to build your own, this
documentation will guide you step by step through the process.

Contents
--------

.. toctree::

    User manual
	Assembly manual
	Troubleshooting

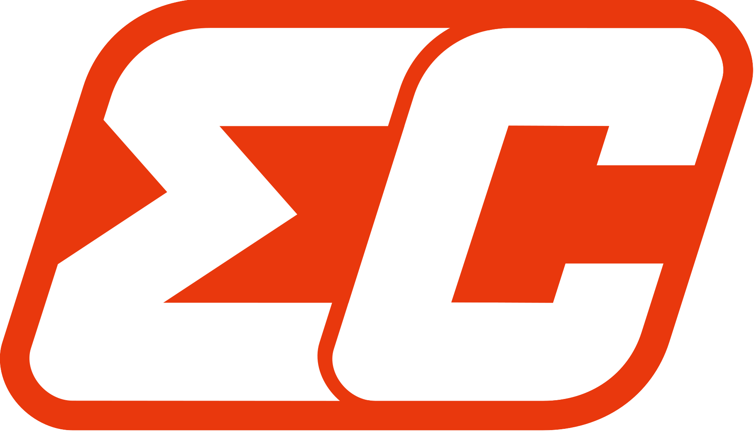
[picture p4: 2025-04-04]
.github/images/symbol_large_transparent_bg_close.png

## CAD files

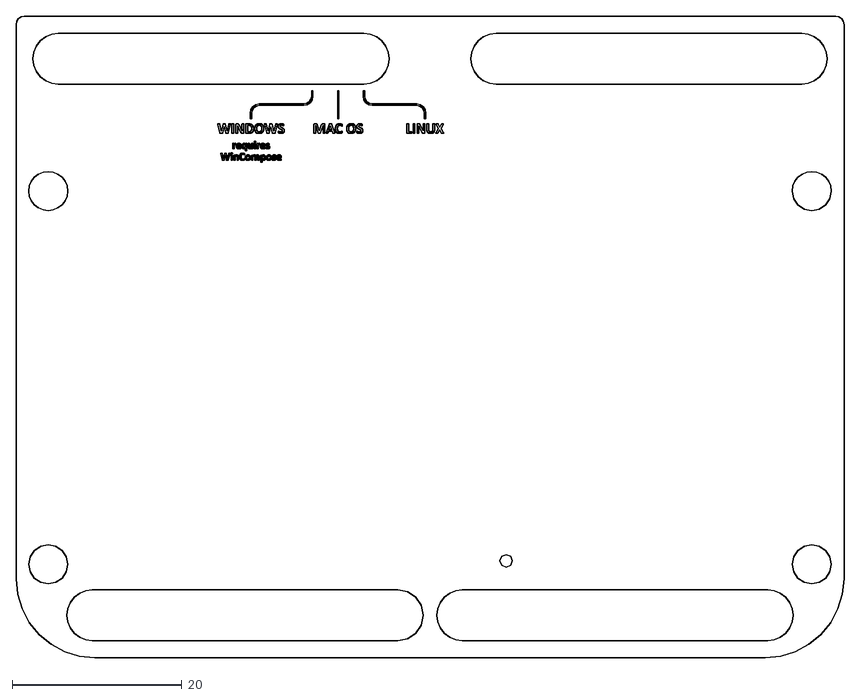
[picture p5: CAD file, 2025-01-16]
hardware/case/laser marking/Bottom laser marking.dxf
97.5 x 75.5

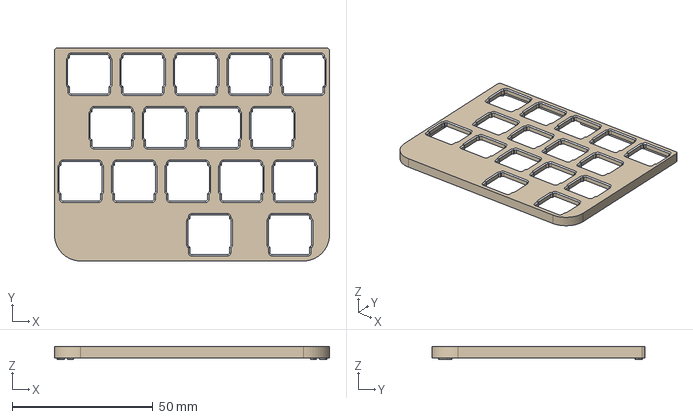
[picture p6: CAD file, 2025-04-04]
hardware/case/Top case.step
97.6 x 75.6 x 4.70 mm

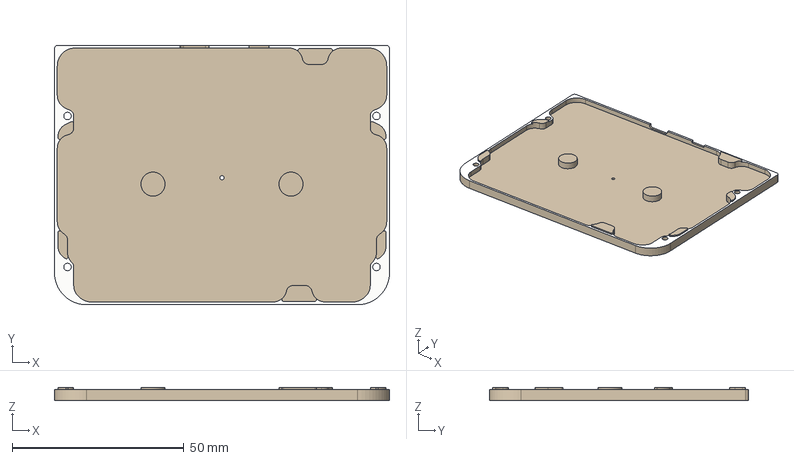
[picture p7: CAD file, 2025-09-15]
hardware/enclosure/cad files/mathpad_enclosure_bottom v1-8.step
97.6 x 75.6 x 3.85 mm

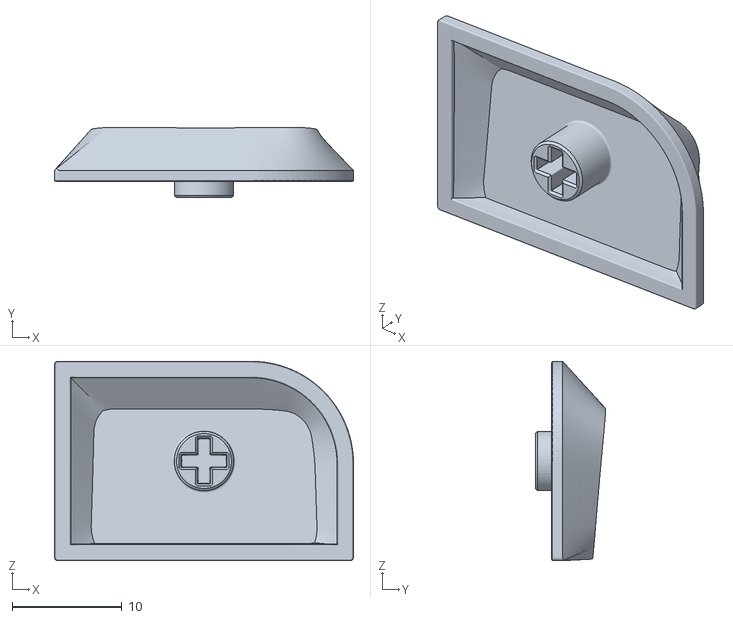
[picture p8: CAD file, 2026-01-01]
hardware/keycaps/cad files/JWA-1-5u-rounded.stl
27.2 x 6.42 x 18.2

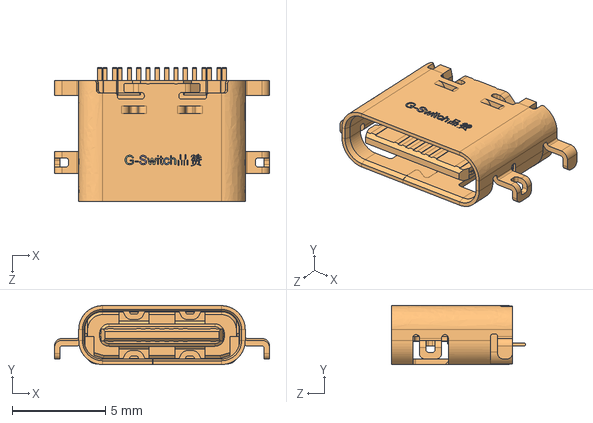
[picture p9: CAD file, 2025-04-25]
hardware/pcb/kicad/resources/3d_models/GT-USB-7014B01.STEP
11.5 x 3.17 x 7.20 mm

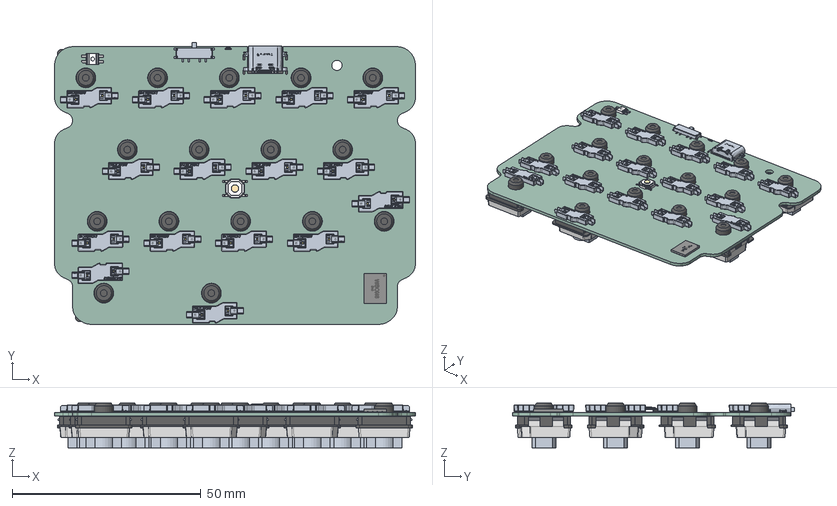
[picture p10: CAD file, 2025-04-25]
hardware/pcb/mathpad_pcb_rev_1-7.step
95.6 x 74.6 x 11.8 mm
CQ assembly x 16
RD-016DC2F7Ahmfr x 16
GT-USB-7014B01
WSON8-8x6
TS-1187A v2
D284A1DE-DC6D-4158-B55F-1EC0D55C8087
Pins
_autosave-Mathpad_PCB

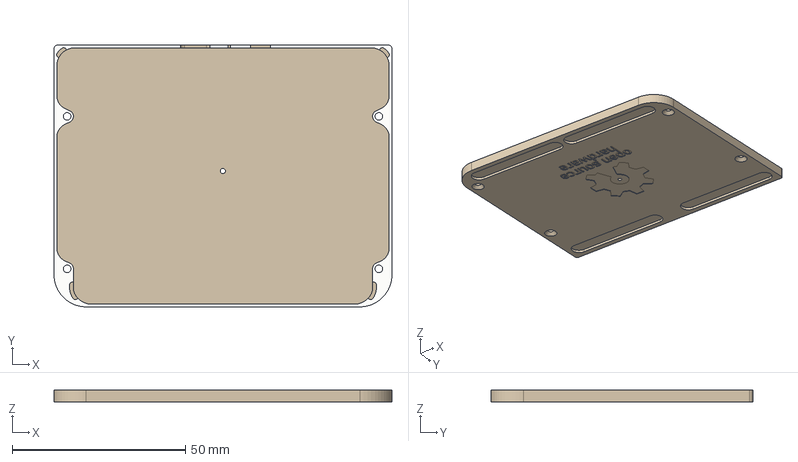
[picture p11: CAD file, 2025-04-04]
hardware/case/Bottom case.step
97.6 x 75.6 x 3.50 mm

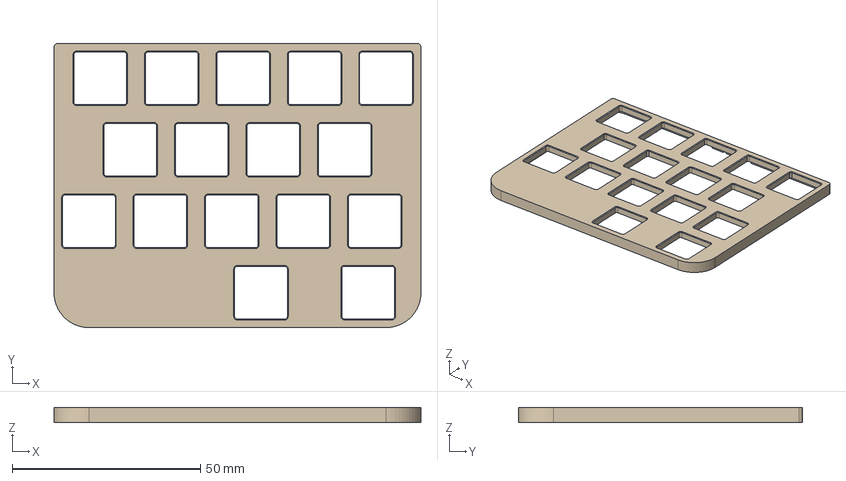
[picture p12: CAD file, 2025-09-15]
hardware/enclosure/cad files/mathpad_enclosure_top v1-8.step
97.6 x 75.6 x 3.98 mm

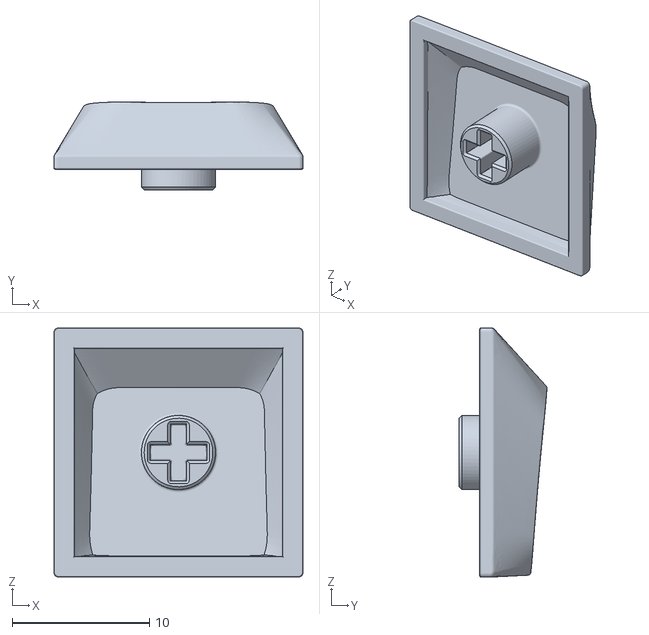
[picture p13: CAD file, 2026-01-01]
hardware/keycaps/cad files/JWA-1u.stl
18.1 x 6.41 x 18.1

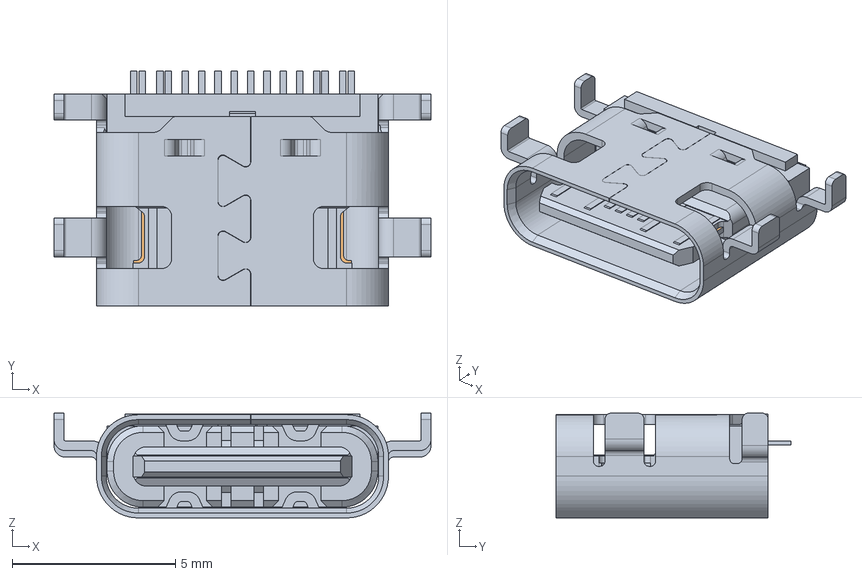
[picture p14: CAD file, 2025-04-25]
hardware/pcb/kicad/resources/3d_models/TYPE-C 16P 0.8 3MD 073.step
11.5 x 7.20 x 3.21 mm

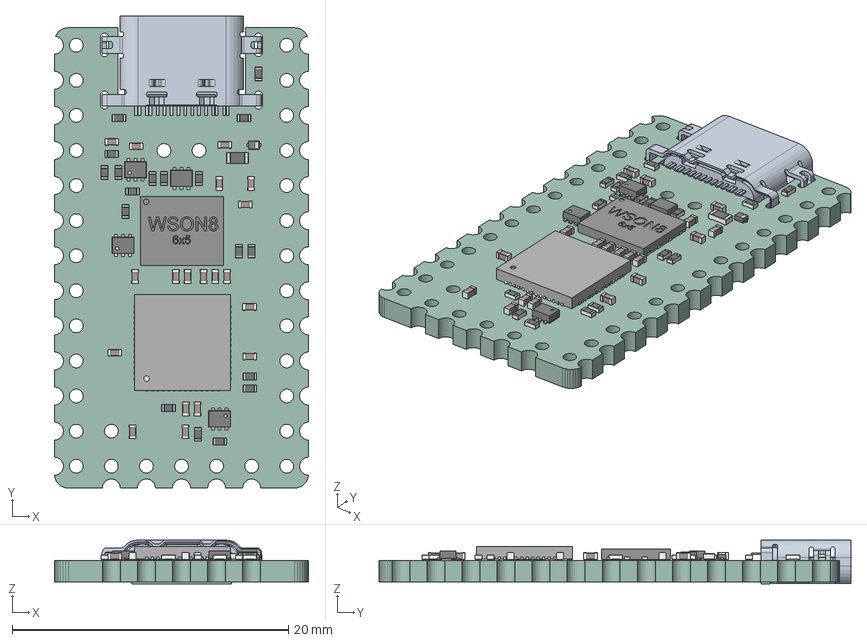
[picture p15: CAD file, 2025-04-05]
hardware/pcb/kicad/resources/3d_models/helios.step
18.4 x 34.2 x 3.18 mm
_autosave-helios PCB

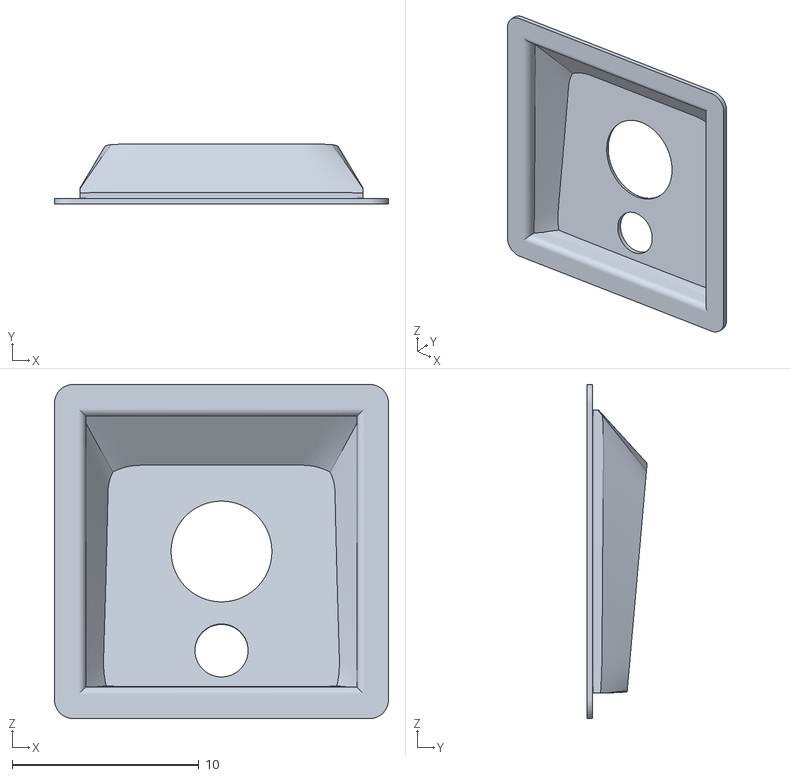
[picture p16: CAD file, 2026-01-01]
hardware/keycaps/cad files/Mode-Switch-Insert.stl
17.9 x 3.23 x 17.9

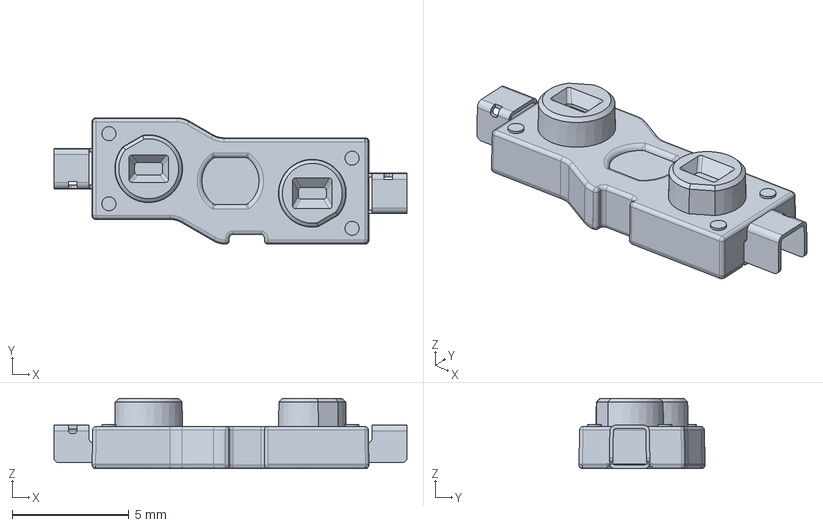
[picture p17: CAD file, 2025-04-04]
hardware/pcb/kicad/resources/3d_models/ks-2p02b01-02.stp
15.1 x 5.39 x 3.00 mm

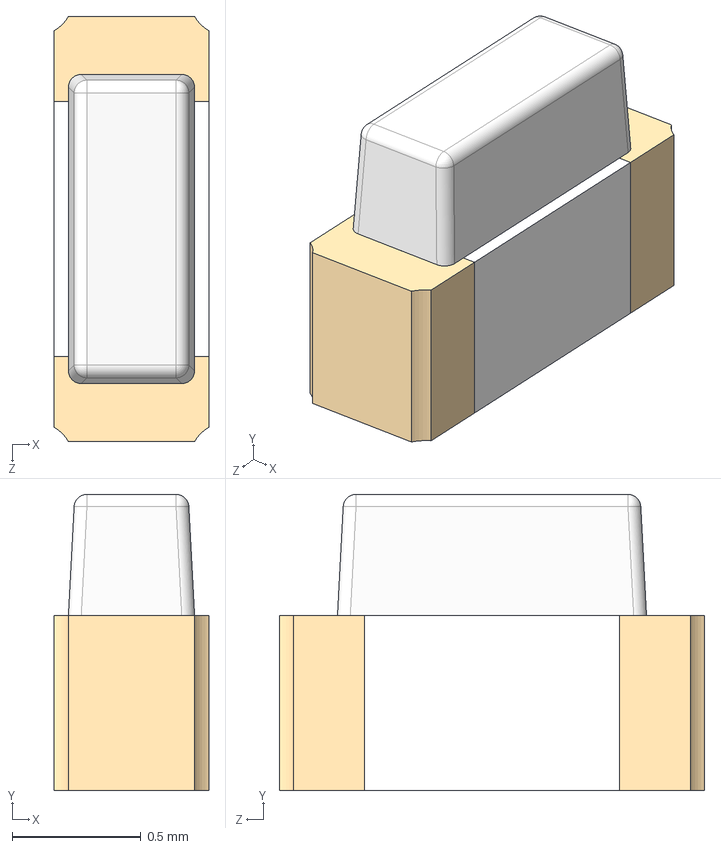
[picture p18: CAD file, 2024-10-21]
hardware/pcb/kicad/resources/3d_models/0603 side view led.step
0.6 x 1.15 x 1.65 mm

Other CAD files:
hardware/keycaps/cad files/JWA-1-5u.stl
hardware/keycaps/cad files/JWA-1u-Mode-Switch.stl
hardware/pcb/kicad/resources/3d_models/xb-msk-103.stp
hardware/pcb/kicad/resources/3d_models/3303W-3.step
hardware/keycaps/cad files/JWA-15u-rounded.stl
hardware/pcb/kicad/resources/3d_models/SK6812MINI-E v1.step
hardware/pcb/kicad/resources/3d_models/TS-1187A.step
hardware/pcb/kicad/resources/3d_models/USB - C inboard.STEP
hardware/pcb/kicad/resources/3d_models/WSON8-8x6.STEP
hardware/pcb/kicad/resources/3d_models/ks33.step

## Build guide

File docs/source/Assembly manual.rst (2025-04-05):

Assembly manual
###############
This page lists every component of the Mathpad and how to assemble them.

**Components** :

* 1x Mathpad PCB TODO: Add PCBs to Tindie
* 16x `Gateron KS-33 Low Profile v2 switches <https://www.gateron.co/products/gateron-low-profile-mechanical-switch-set>`_
* 1x Mathpad case TODO: Sell on Tindie?
* 1x Keycap set TODO: Ask Loic to add this to his webstore?
* 4x `M2 x 6mm countersunk screws <https://www.accu.co.uk/phillips-countersunk-screws/175101-SIK-M2-6-A2-BL>`_
* 1x `M2.5 x 3mm Pan Head screw <https://www.accu.co.uk/metric-pan-head-screws/6949-SFP-M2-5-3-A2>`_
* 4x SKUF rubber feet

**Assembly** : 
TODO: Document the assembly process

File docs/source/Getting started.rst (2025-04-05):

Getting started
###############

Make sure you have already followed the instructions in :ref:`first_setup`.

Accessing the Mathpad symbols
===============================
The Mathpad packs a lot of symbols onto a small keyboard by placing more than one symbol on each key. When
you click a key, it will output one of its six symbols depending on the state of the modifier keys.

There are three modifier keys: Blue, Green and Purple. The Blue modifier key accesses the symbols on the right 
side of each key. The Green modifier key accesses the bottom row of symbols, located on the front face. The 
Purple modifier key accesses the middle row of symbols. You can combine the Blue and Green/Purple modifier keys to 
access any symbol.

When no modifier keys are pressed, clicking a key outputs left symbol of the black upper row of that key.

Multitap symbols
================
Certain symbols are marked by a small orange dot. Double-tapping such a symbol will output a different, but related,
symbol than what's printed on the keycap. For example, double tapping λ produces Λ. Double tapping ω produces Ω.

Certain symbols can be tapped more than twice. For example, double- and triple-tapping √ gives you ∛ and ∜.

Switching between modes
=======================
The Mathpad can switch between three modes: Unicode, LaTeX, and Microsoft Office Equations Editor. The current mode is
indicated by the LED with the following color codes:

- Blue: Unicode
- Yellow: LaTeX
- Purple: Microsoft Office Equations Editor

Many symbols will be output differently depending on which mode is selected.

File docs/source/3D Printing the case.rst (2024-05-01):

3D printing parts
#################
.. note::
    Prerequisites:

    * A 3D Printer
    * PLA of any color for the case
    * White PLA for the LED diffuser

Printing the case and diffuser
==============================
Open your slicer software and import the following two Mathboard case files:

* \hardware\case\Bottom.stl
* \hardware\case\Lid.stl

They can be printed at the same time using the same settings. They are simple parts, and should be printable with the
default settings of your slicer. **Ensure that Lid.stl is printed upside down on the print bed**, as shown here:

TODO: Insert image

Once the bottom and lid have been printed, move on to the diffuser. Import the following file in your slicer software:

* \hardware\case\Diffuser.stl

This part must be printed with white filament to allow the status LED to shine through.

Printing the keycap risers
===========================
.. note::
    These keycap risers are only needed if you are using OEM R2 keycaps.

The keycap risers exist to make the OEM R2 keycaps compatible with the low profile Gateron switches. They raise the
keycaps up by 1mm so that they do not crash into the top of the Mathboard before the switch has been fully pressed.

You will need 16 of these keycap risers, one for each switch on the mathboard. Import the following file in your
slicer software:

* \hardware\case\Keycap risers.stl

The keycap risers are very small components with tight tolerances, and may require some tuning to print correctly. I
have personally had success with the following settings:

* Layer height : 0.2mm
* Skirt : Yes
* Speed : 20% of normal

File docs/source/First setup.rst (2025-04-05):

.. _first_setup:

First setup of the Mathpad
============================
The Mathpad *almost* works straight out of the box, but there are some initial setup tasks that must be performed.
These tasks will depend on the computer that you intend to use your Mathpad with.

Software
########
If you intend to use your Mathpad on an Apple Mac or any Linux-based operating system, you can skip to the Firmware
section. If you intend to use the Mathpad on a Windows computer, you must first
install the lightweight application `WinCompose <http://wincompose.info>`_ which provides support for Unicode input.

Firmware
########
The firmware of the Mathpad must match the keyboard layout of the computer on which you intend to use it with.
This is an inescapable consequence of both how operating systems interpret keycodes from keyboards, and the inability of a USB peripheral to automatically deduce the keyboard layout of the computer it is plugged in to.

You must therefore upload, or "flash", a version of the firmware that matches your keyboard layout. Start by figuring
out your keyboard layout (google can help you here). Then go to the
`latest release <https://github.com/nup002/Mathpad/releases>`_ and download the firmware file for your
keyboard layout. Then, plug in the Mathpad and press the reset button (found on the bottom) for at least
half a second. When you release the reset button, a folder will open on your computer. Place the firmware file
in this folder to flash it to the Mathpad. The folder will automatically close when finished, and the Mathpad will
reboot. Done!

.. warning::
    Since the Mathpad is not fully released yet you must build your own firmware if you use a keyboard layout other
    than US ANSI.

Setting the OS switch
#####################
Each operating system [OS] interprets Unicode input differently. The Mathpad must therefore be configured to
output Unicode that the OS can understand. Using the illustration on the bottom of the Mathpad, place the OS switch on
the back of the Mathpad to the OS your computer is running.

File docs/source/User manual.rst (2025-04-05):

.. _user_manual:

Mathpad user manual
=====================
To set up your Mathpad for the first time, see :ref:`first_setup`.

.. toctree::

    First setup
    Getting started

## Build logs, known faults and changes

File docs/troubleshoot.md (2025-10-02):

# Troubleshooting

**Having trouble with your Mathpad? This page might help.**

>[!TIP]
>If you hold down all three modifier keys (blue, purple, and green) for at least 5 seconds and release them, Mathpad will 
>type a lot of helpful information about itself that may aid with debugging. 
> 

## Nothing Happens When I Click Any Key
If you get nothing at all when you click any of the symbol keys, do the following: 
 1) Check that the OS switch on the back of your Mathpad matches the operating system of the computer it is plugged into. 
 2) If you're using Windows, ensure that WinCompose is running and using default settings. 
 3) If you're on a Mac, ensure that Mathpad Service is installed and has been granted  Accessibility permission.

Refer to the [Initial Setup](/init.md) guide for more details. 

## Mathpad Types Nonsense
If your Mathpad types out nonsensical text or completely incorrect symbols, it is likely because your Mathpad's 
firmware does not match your computer's keyboard layout. Refer to [Initial Setup](#/init?id=what-is-your-keyboard-layout).

## Symbols Appear as Question Marks, Empty Boxes, or Normal Letters
This problem is not caused by Mathpad, but by the font you are using. Some fonts simply does not define the 
mathematical symbols that Mathpad can type, so even if they are transmitted correctly to the computer, they cannot 
be displayed by your font. To fix this problem, switch to a font that supports mathematical Unicode symbols. Refer to 
[compatibility](/compatibility.md#fonts).

## General troubleshooting
1. Verify your keyboard layout is [supported](/compatibility.md#supported-keyboard-layouts)
2. Verify you have installed the firmware that matches your keyboard layout
3. Verify the OS switch on the back of Mathpad matches your operating system
4. If using Windows, ensure WinCompose is installed and running
5. If using Mac, ensure that Mathpad Service is installed, running, and has been given accessibility permissions
6. If using Linux, ensure IBus is installed and running
7. Try disconnecting and reconnecting Mathpad
8. Check that Unicode fonts are properly installed on your system

## Still having problems?
Ask your question in the [Mathpad Forum](https://www.summacogni.com/forum/viewforum.php?f=3&sid=c0af401a0636b960e1b51769f60db79d)

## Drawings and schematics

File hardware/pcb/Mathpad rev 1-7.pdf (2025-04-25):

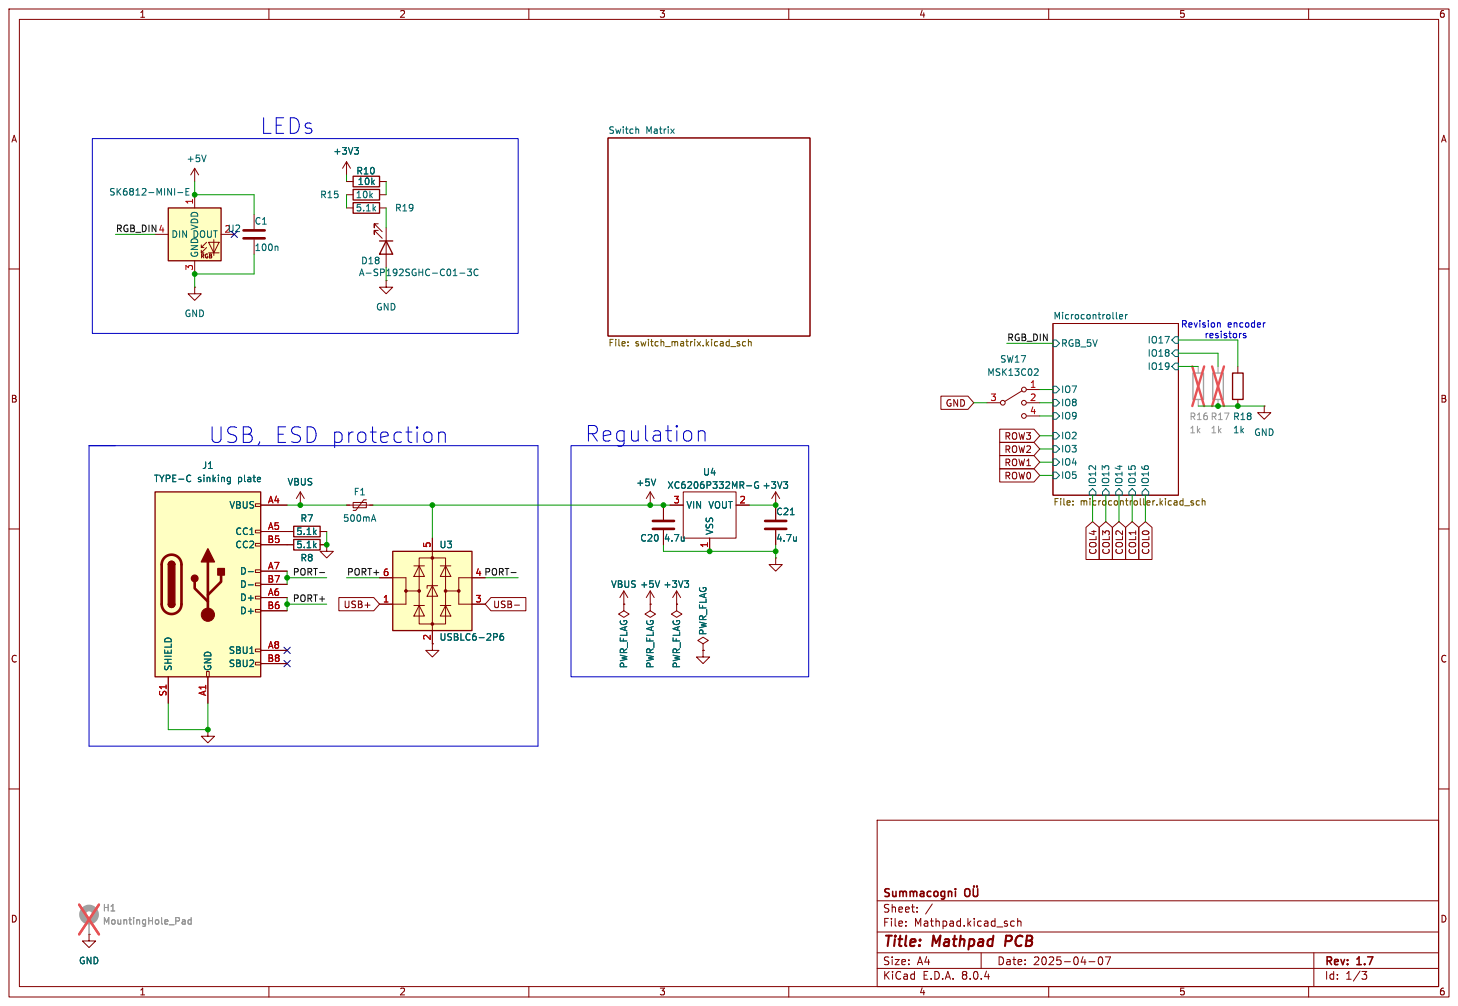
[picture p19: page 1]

Id: 1/3 Title: Mathpad PCB

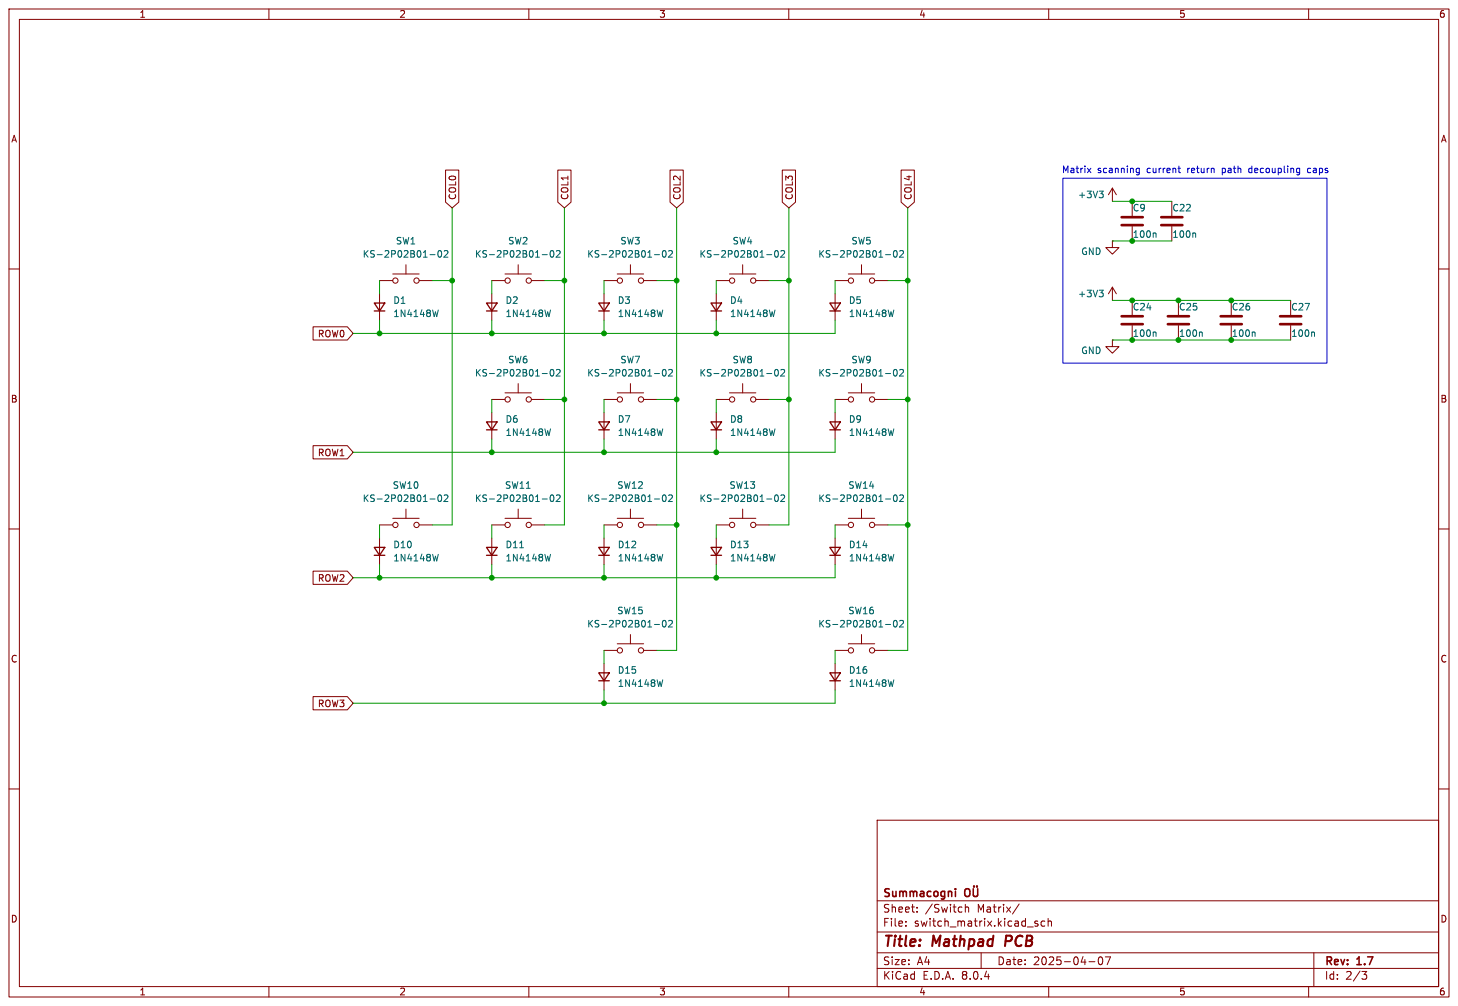
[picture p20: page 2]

Id: 2/3 Title: Mathpad PCB

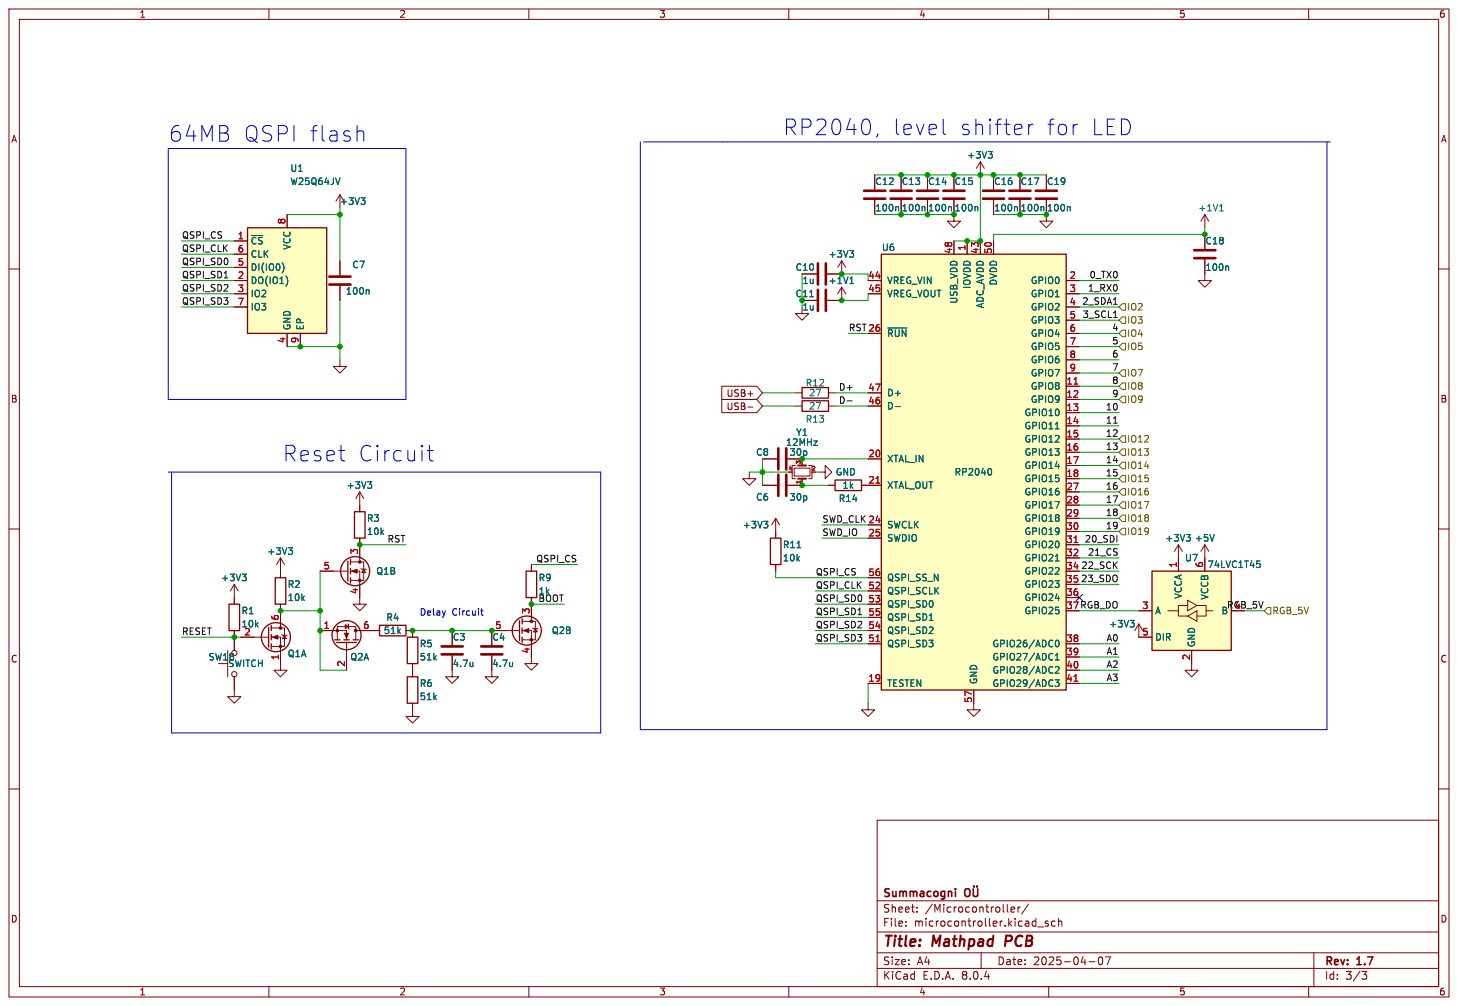
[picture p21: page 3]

1 GPIO8 11 GPIO9 12 GPIO10 13 GPIO11 14 GPIO12 15 GPIO13 16 GPIO14 17 GPIO15 18 TESTEN 19 GPIO0 2 XTAL_IN 20 XTAL_OUT 21 SWCLK 24 SWDIO 25 ~{RUN} 26 GPIO16 27 GPIO17 28 GPIO18 29 GPIO1 3 GPIO19 30 GPIO20 31 GPIO21 32 GPIO22 34 GPIO23 35 GPIO24 36 GPIO25 37 GPIO26/ADC0 38 GPIO27/ADC1 39 GPIO2 4 GPIO28/ADC2 40 GPIO29/ADC3 41 ADC_AVDD 43 VREG_VIN 44 VREG_VOUT 45 D- 46 D+ 47 USB_VDD 48 GPIO3 5 DVDD 50 QSPI_SD3 51 QSPI_SCLK 52 QSPI_SD0 53 QSPI_SD2 54 QSPI_SD1 55 QSPI_SS_N 56 GND 57 GPIO4 6 GPIO5 7 GPIO6 8 GPIO7 9 GND

File: microcontroller.kicad_sch Sheet: /Microcontroller/ Summacogni þÿOÜ

Id: 3/3 Title: Mathpad PCB

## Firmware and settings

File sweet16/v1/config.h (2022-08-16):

#pragma once

#include "config_common.h"

/* USB Device descriptor parameter */
#define PRODUCT_ID      0x0161
#define DEVICE_VER      0x0001

/* key matrix pins */
#define MATRIX_ROW_PINS { F4, F5, F6, F7 }
#define MATRIX_COL_PINS { D1, D0, D4, C6 }
#define UNUSED_PINS

/* COL2ROW or ROW2COL */
#define DIODE_DIRECTION COL2ROW

/* Set 0 if debouncing isn't needed */
#define DEBOUNCE 5

#ifndef CONVERT_TO_PROTON_C
#    define LED_NUM_LOCK_PIN B0 // RXLED
#    define LED_CAPS_LOCK_PIN D5 // TXLED
#    define LED_PIN_ON_STATE 0
#endif

/* Underglow options */
#define RGB_DI_PIN B1
#ifdef RGB_DI_PIN
#define RGBLIGHT_ANIMATIONS
#define RGBLED_NUM 1
#define RGBLIGHT_HUE_STEP 8
#define RGBLIGHT_SAT_STEP 8
#define RGBLIGHT_VAL_STEP 8
#endif

/* Unicode input mode */
#define UNICODE_SELECTED_MODES UC_WINC

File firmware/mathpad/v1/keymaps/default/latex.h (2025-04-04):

/* Copyright 2023 Magne Lauritzen
 *
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
 * You should have received a copy of the GNU General Public License
 * along with this program.  If not, see <http://www.gnu.org/licenses/>.
 */

// Definitions specifically for LaTeX

#ifndef LATEX_H
#define LATEX_H

// Greek letters
#define alpha_LTX   "\\alpha"
#define beta_LTX    "\\beta"
#define gamma_LTX   "\\gamma"
#define Gamma_LTX   "\\Gamma"
#define delta_LTX   "\\delta"
#define Delta_LTX   "\\Delta"
#define epsilon_LTX "\\epsilon"
#define zeta_LTX    "\\zeta"
#define eta_LTX     "\\eta"
#define theta_LTX   "\\theta"
#define Theta_LTX   "\\Theta"
#define iota_LTX    "\\iota"
#define kappa_LTX   "\\kappa"
#define lambda_LTX  "\\lambda"
#define Lambda_LTX  "\\Lambda"
#define mu_LTX      "\\mu"
#define nu_LTX      "\\nu"
#define xi_LTX      "\\xi"
#define Xi_LTX      "\\Xi"
#define omicron_LTX "\\αmathrm{o}"
#define pi_LTX      "\\pi"
#define Pi_LTX      "\\Pi"
#define rho_LTX     "\\rho"
#define sigma_LTX   "\\sigma"
#define Sigma_LTX   "\\Sigma"
#define tau_LTX     "\\tau"
#define upsilon_LTX "\\upsilon"
#define phi_LTX     "\\phi"
#define varphi_LTX  "\\varphi"
#define Phi_LTX     "\\Phi"
#define chi_LTX     "\\chi"
#define psi_LTX     "\\psi"
#define Psi_LTX     "\\Psi"
#define omega_LTX   "\\omega"
#define Omega_LTX   "\\Omega"

// Comparison and equivalence
#define notequal_LTX   "\\neq"
#define almostequal_LTX   "\\approx"
#define proportional_LTX   "\\propto"
#define identicalto_LTX   "\\equiv"
#define lessorequal_LTX   "\\leq"
#define greaterorequal_LTX   "\\geq"
#define much_greater_than_LTX   "\\gg"
#define much_much_greater_than_LTX   "\\ggg"
#define much_less_than_LTX   "\\ll"
#define much_much_less_than_LTX   "\\lll"

// Modifiers
#define circumflex_LTX   "\\hat{}"
#define check_LTX   "\\check{}"
#define combining_tilde_LTX   "\\tilde{}"
#define combining_bar_LTX   "\\bar{}"
#define combining_arrow_LTX   "\\vec{}"
#define combining_dot_LTX   "\\dot{}"
#define combining_2dot_LTX   "\\ddot{}"
#define prime_LTX   "\\prime" // not in use currently
#define transposed_LTX   "^\\top"
#define sup_0_LTX   "^{0}"
#define sup_1_LTX   "^{1}"
#define sup_2_LTX   "^{2}"
#define sup_n_LTX   "^{n}"
#define sup_i_LTX   "^{i}"
#define sup_j_LTX   "^{j}"
#define sub_0_LTX   "_{0}"
#define sub_1_LTX   "_{1}"
#define sub_2_LTX   "_{2}"
#define sub_n_LTX   "_{n}"
#define sub_i_LTX   "_{i}"
#define sub_j_LTX   "_{j}"

// Algebra and calculus
#define sum_LTX   "\\sum_{}^{}"
#define n_ary_product_LTX   "\\prod_{}^{}"
#define integral_LTX   "\\int_{}^{}"
#define double_integral_LTX   "\\iint_{}^{}"
#define triple_integral_LTX   "\\iiint_{}^{}"
#define line_integral_LTX   "\\oint_{}^{}"
#define surface_integral_LTX   "\\oiint_{}^{}" // Requires one of wasysym, esint, pxfonts
#define volume_integral_LTX   "\\oiiint_{}^{}" // Requires pxfonts
#define square_root_LTX   "\\sqrt{}"
#define cube_root_LTX   "\\sqrt[3]{}"
#define fourth_root_LTX   "\\sqrt[4]{}"
#define arrow_LTX   "\\rightarrow"
#define partial_derivative_LTX   "\\partial"
#define nabla_LTX   "\\nabla"

// Set theory 
#define union_LTX   "\\bigcup_{}^{}"
#define intersection_LTX   "\\bigcap_{}^{}"
#define element_of_LTX   "\\in"
#define not_element_of_LTX   "\\notin"
#define empty_set_LTX   "\\varnothing" // Requires amssymb
#define subset_of_LTX   "\\subset"
#define not_subset_of_LTX   "\\not\\subset"
#define set_difference_LTX   "\\setminus"
#define subset_or_equal_LTX   "\\subseteq"
#define not_subset_or_equal_LTX   "\\nsubseteq"
#define disjoint_union_LTX   "\\sqcup"

// Logic
#define arrow_implies_LTX   "\\Rightarrow"
#define arrow_if_and_only_if_LTX   "\\Leftrightarrow"
#define there_exists_LTX   "\\exists"
#define there_does_not_exist_LTX   "\\nexists"
#define and_LTX   "\\wedge"
#define or_LTX   "\\vee"
#define xor_LTX   "\\veebar"
#define for_all_LTX   "\\forall"
#define unconditionally_true_LTX   "\\top"
#define unconditionally_false_LTX   "\\bot"
#define not_LTX   "\\neg"
#define proves_LTX   "\\vdash"
#define models_LTX   "\\models"

// Others
#define dotproduct_LTX   "\\cdot"
#define crossproduct_LTX   "\\times"
#define plusminus_LTX   "\\pm"
#define minusplus_LTX   "\\mp"
#define parallel_LTX   "\\parallel"
#define degree_LTX   "\\degree"
#define infinity_LTX   "\\infty"
#define matrix_LTX  "\\begin{bmatrix} a & b \\\\ c & d \\end{bmatrix}" // Requires amsmath
#define frac_LTX  "\\frac{}{}"

#define LTX_FLAG "LATEX: "

void send_and_backtrack_4(const char *string){
    //send_string(string);
    send_string(string);
    for (int i = 0; i < 4; ++i){tap_code(KC_LEFT);}
}

void send_and_backtrack_3(const char *string){
    //send_string(string);
    send_string(string);
    tap_code(KC_LEFT);
}

void send_and_backtrack_1(const char *string){
    //send_string(string);
    send_string(string);
    tap_code(KC_LEFT);
}

void send_latex(const char *string){
    // Else-if for special characters. Cannot use case switch structure because the defined latex strings are not constants.
    if (!strcmp(string, sum_LTX)){send_and_backtrack_4(string);}
    else if (!strcmp(string, n_ary_product_LTX)){send_and_backtrack_4(string);}
    else if (!strcmp(string, integral_LTX)){send_and_backtrack_4(string);}
    else if (!strcmp(string, double_integral_LTX)){send_and_backtrack_4(string);}
    else if (!strcmp(string, triple_integral_LTX)){send_and_backtrack_4(string);}
    else if (!strcmp(string, line_integral_LTX)){send_and_backtrack_4(string);}
    else if (!strcmp(string, surface_integral_LTX)){send_and_backtrack_4(string);}
    else if (!strcmp(string, volume_integral_LTX)){send_and_backtrack_4(string);}
    else if (!strcmp(string, square_root_LTX)){send_and_backtrack_1(string);}
    else if (!strcmp(string, cube_root_LTX)){send_and_backtrack_1(string);}
    else if (!strcmp(string, fourth_root_LTX)){send_and_backtrack_1(string);}
    else if (!strcmp(string, union_LTX)){send_and_backtrack_4(string);}
    else if (!strcmp(string, intersection_LTX)){send_and_backtrack_4(string);}
    else if (!strcmp(string, frac_LTX)){send_and_backtrack_3(string);}
    else if(strlen(string) > 2 && !strcmp(string + strlen(string) - 2, "{}")) {
        // In this case the string is meant to wrap around the previous character
        tap_code(KC_LEFT);
        // Create a new string that contains the original string up to the last curly brace
        char substring[strlen(string)];
        memcpy(substring, &string[0], strlen(string)-1);
        substring[strlen(string)-1] = '\0';
        send_string(substring);
        tap_code(KC_RIGHT);
        // Send the final curly brace
        tap_code16(KC_RIGHT_CURLY_BRACE);
    } else {
        send_string(string);
    }
}

void send_latex_on_keypress(const char *string, keyrecord_t *record){
    if (record->event.pressed) {
        send_latex(string);
    };
};

#endif

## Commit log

2022-08-16 First commit
    Commit of firmware for Sweet 16 based prototype
2022-09-15 Began implementation of mode switching
2023-12-31 Preparing for release of version 1
    [BOM.csv, Bottom case.step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]
2023-12-31 Fix licenses and update readme
    [JLCPCB_BOM.csv, bottom.step, lid.step]
2024-02-01 various updates
    [Bottom.stl, Lid.stl, bottom.step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]
2024-02-03 Update .gitignore
    Modify gitignore to not keep:
    * Kicad backup files
    * .lck files
    * the .idea folder
2024-02-03 Bugfix: Set unicode mode switch pole to GND instead of VDD
    [Mathboard.kicad_pcb, Mathboard.kicad_sch]
2024-02-04 Uicode mode switching
2024-02-05 Status LED color
2024-02-10 Update Bill of Materials and Tools.md
    Make list of items
2024-02-18 LED diffuser
    [Bottom.stl, Diffuser.stl]
2024-02-18 Screw hole changes for better printing
    [Lid.stl]
2024-02-18 LED light fixes and lower brightness
    [config.h]
2024-02-18 Add acrylate glue and reformatting
2024-02-18 Add switches and link to LED
2024-03-17 Fix dip switch order
2024-03-17 Keycap riser
    [Keycap riser.stl]
2024-03-17 UV printing fixtures
    [OEM R2 front face fixture.stl, OEM R2 top face fixture.stl]
2024-04-27 Assembly manual
2024-04-27 Make assembly holes larger
    [Mathboard.kicad_pcb, Mathboard.kicad_sch]
2024-04-30 Update PCB and production files to revision 2
    [JLCPCB_BOM.csv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]
2024-05-01 More documentation
    [Keycap riser.stl, Keycap risers.stl]
2024-05-03 Remove unecessary led
2024-05-23 Pictures of PCB rev 2
2024-05-25 dip switch changes for pcb revision 2
2024-05-26 Add Tindie link for PCB
2024-09-27 Progress towards version 2
    [Mathboard.kicad_pcb, Mathboard.kicad_sch, TS-1187A.step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]
2024-10-01 Version 2 sent to production
    [BOM.csv, JLCPCB_BOM.csv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]
2024-10-21 Revision 4
    [0603 side view led.step, 3303W-3.step, BOM.csv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]
2024-11-08 Fixtures no longer required
    [OEM R2 front face fixture.stl, OEM R2 top face fixture.stl]
2024-11-12 Logo fixes and laser marking files
    [Top laser marking.dxf, Top outline.dxf, logo.dxf]
2024-11-12 Create back laser marking files
    [Back laser marking.dxf, Back outline.dxf, Top laser marking.dxf]
2024-11-13 Fix laser marking files
    [Back laser marking.dxf, Back outline.dxf, Top laser marking.dxf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]
2024-11-25 Changes for pcb version 1.4
2024-11-26 Added version encoder resistors
    [Mathboard.kicad_pcb, Mathboard.kicad_sch, microcontroller.kicad_sch]
2025-01-14 V1.5
    Minor changes:
    Recessed the USB port
    Removed ESD warning label
    Moved the reset button to the center
    [Mathboard.kicad_pcb]
2025-01-15 USB port fixed
    [Mathboard.kicad_pcb, Mathboard.step]
2025-01-16 V1.5 gerbers and changes to the USB layout
    [Mathboard-B_Cu.gbl, Mathboard-B_Mask.gbs, Mathboard-B_Paste.gbp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]
2025-01-28 Better EMC and ESD safety
    [Mathboard.kicad_pcb, Mathboard.kicad_sch, microcontroller.kicad_sch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]
2025-01-29 ESD case grounding
    [Mathboard.kicad_pcb, Mathboard.kicad_sch]
2025-02-11 Minor changes for v1.5
    [Mathboard.kicad_pcb, Mathboard.kicad_sch, Mathboard.step]
2025-02-13 Version 1.5
    [BOM.csv, Bottom case.step, Bottom case.stl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]
2025-02-15 Update laser markings
    [Back laser marking.dxf, Bottom case.step, Front laser marking.dxf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]
2025-04-04 Hotswap sockets and fw improvements
    [Bottom case.step, Mathboard.kicad_pcb, Mathboard.kicad_sch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]
2025-04-05 Rebrand from Mathboard to Mathpad
    [0603 side view led.step, 3303W-3.step, Mathboard.step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]
2025-04-05 Remove old Mathboard kicad project
    [0603 side view led.step, 3303W-3.step, BOM.csv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]
2025-04-05 Rebranding to Mathpad
    [BOM.csv, Mathpad.kicad_pcb, Mathpad.kicad_sch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]
2025-04-05 Schematics for v1.6
2025-04-05 Remove logos as they are not permitted for replication
    [logo.dxf]
2025-04-07 Reformatting, removing old files, add better documentation about licenses
    [0603 side view led.step, 3303W-3.step, BOM.csv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]
2025-04-08 Debugging the layer switching
2025-04-11 minor fixes
    [Mathpad.kicad_pcb, mathpad_pcb_v1-6.step, microcontroller.kicad_sch]
2025-04-14 Minor modifications to the pcb
    [Mathpad.kicad_pcb, Mathpad.kicad_sch, microcontroller.kicad_sch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]
2025-04-14 Update step files to v1.6
    [mathpad_enclosure_bottom.step, mathpad_enclosure_top.step]
2025-04-15 Put hotswap socket on the correct layer
    [Mathpad.kicad_pcb, switch_matrix.kicad_sch]
2025-04-25 ChangePCB thickness to 1mm
    [GT-USB-7014B01.STEP, Mathpad.kicad_pcb, Mathpad.kicad_sch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]
2025-04-28 Reset button illustration
2025-04-29 Reactive landing page
2025-05-07 Add keepout areas for PCB support
    [Mathpad.kicad_pcb, mathpad_enclosure_bottom.step, mathpad_enclosure_top.step]
2025-05-07 Added nice buttons to the Readme.
2025-05-08 Update readme.md
    Make top buttons on the same line
2025-05-22 Implement our very own PID code!
2025-05-27 Add missing symbol ÷ and change name of ⊕ to direct sum
2025-06-24 Add MPN and purchase links to all components
    [Mathpad.kicad_sch, microcontroller.kicad_sch, switch_matrix.kicad_sch]
2025-07-03 Replace \bar with \overline
    [latex.h]
2025-07-18 Large formatting
    [Mathpad.kicad_pcb]
2025-07-29 Reworking the mode switch light
    [config.h]
2025-07-29 Implementing custom MODE switch brightness control
2025-07-30 Mode switch brightness control
2025-08-21 print debug info after holding all modifier keys for 5 seconds
2025-08-21 Add debug info printer functions
2025-08-21 Auto-generate build info for the debug print
2025-08-23 Add sticky modifier keys option. Fix sendstring header include.
    [config.h, info.c]
2025-09-07 Update enclosure outlines and laser markings
    [Mathpad.kicad_pcb]
2025-09-07 Better dialog flow and custom icon
2025-09-15 New enclosure version 1.8
    [mathpad_enclosure_bottom v1-8.step, mathpad_enclosure_bottom.step, mathpad_enclosure_top v1-8.step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]
2025-09-15 Add stackup info
    [Mathpad.kicad_pcb]
2025-09-15 remove assembly manual and add software download page
2025-09-15 remove assembly manual
2025-09-21 Reduce sidebar width. Disable zoomable landing page logo. Add search plugin.
2025-11-27 Rename 'reset button' to 'restart button'
2025-11-28 Add a tip about how to get the current mathpad fw version
2026-01-01 Add missing keycap files
    [JWA-1-5u-rounded.stl, JWA-1-5u.stl, JWA-1u-Mode-Switch.stl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]

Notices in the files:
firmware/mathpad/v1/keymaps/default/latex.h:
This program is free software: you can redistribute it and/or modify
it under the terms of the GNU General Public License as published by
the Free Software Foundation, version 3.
